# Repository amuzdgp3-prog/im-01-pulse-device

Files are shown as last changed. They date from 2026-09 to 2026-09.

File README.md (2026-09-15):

# ИМ-01 — устройство учёта импульсов для игровых аппаратов

Отдельный модуль к системе обслуживания аппаратов `2.apixspb.ru`. Устройство слушает импульсные
выходы монетоприёмника и купюроприёмника, копит показания в FRAM и дважды в сутки передаёт их на
сервер по LTE Cat.1. Показания идут **параллельно** ручным и в финансовую историю не пишутся.

Полное задание и спецификация: [docs/IM-01_FULL_BRIEF.md](docs/IM-01_FULL_BRIEF.md).

## Где что лежит

| Папка | Что там |
| --- | --- |
| `docs/` | задание, отчёты по шагам проверки, графики |
| `sim/` | аналоговая симуляция (ngspice): схемы, прогонщик, сводка результатов |
| `firmware/` | прошивка MCU (шаг 3, пока пусто) |
| `hardware/` | проект KiCad (шаг 5, пока пусто) |
| `server-contract/` | заметки по серверной части; сама реализация — в репозитории `2.apixspb.ru` (шаг 2) |

## Состояние по плану проверки (§9)

| Шаг | Что | Статус |
| --- | --- | --- |
| 1 | Аналоговая симуляция | **сделан** — [отчёт](docs/step1-analog-sim.md); виртуальная модель всего устройства — `sim/run_final.py` |
| 2 | Серверная часть в `2.apixspb.ru` | отложена владельцем: сначала железо |
| 3 | Прошивка в Renode | не начат |
| 4 | Сквозная проверка | не начат |
| 5 | Плата в KiCad | **сделана** — [описание](docs/hardware.md), файлы для JLCPCB в `hardware/fab/`; нужно ревью инженером перед заказом |

Перечень комплектующих с ценами LCSC и в РФ: [docs/ИМ-01_перечень_комплектующих.xlsx](docs/ИМ-01_перечень_комплектующих.xlsx).

## Как повторить симуляцию

```bash
sudo apt-get install -y ngspice
python3 sim/run_sim.py        # ~1 минута; matplotlib — по желанию, для графиков
```

Результат — `sim/results_auto.md` и графики в `sim/out/`.

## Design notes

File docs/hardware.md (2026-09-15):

# ИМ-01 — плата: схема, трассировка, файлы для производства

Ревизия A, 15.09.2026. Всё генерируется из одного файла `hardware/design.py`: схема, плата и перечень
не могут разойтись. Как пересобрать — в конце документа.

## Коротко

- Плата 80×55 мм, 2 слоя, 1.6 мм, 108 элементов, из них 90 монтируются. Всё на верхней стороне.
- Модем **Quectel EG800K-EU** (LTE Cat.1 bis, диапазоны B1/B3/B5/B7/B8/B20/B28).
- Проверки: ERC схемы — 0 ошибок; DRC платы — 0 нарушений; сверка платы со схемой — 0 расхождений.
  Состояние разводки — в конце документа.
- Комплектующие: около 840 ₽ на плату при партии 500 шт. (подробно — в
  [ИМ-01_перечень_комплектующих.xlsx](ИМ-01_перечень_комплектующих.xlsx)).
- Файлы для заказа на JLCPCB — `hardware/fab/`.

**Перед заказом партии в 500 штук плату должен посмотреть глазами инженер-схемотехник** (IM-01 §9
шаг 5: «плату на 500 шт не отправлять в производство без ревью глазами»). Сначала — 5–10 штук на пилот.

## Что на плате

| Блок | Детали | Зачем |
| --- | --- | --- |
| Вход питания 9–30 В | J1 (JST VH), F1 0.5 А/60 В, D1 SS36, D2 SMBJ33A, C1 47 мкФ | предохранитель, защита от переполюсовки и выбросов, гашение звона кабеля |
| Преобразователь | U1 LMR16020 (вход до 60 В), L1 10 мкГн, D3 SS36 | 3.84 В для модема, 600 кГц |
| VBAT модема | C8, C9, C33 — полимер 470 мкФ; массив 22 мкФ…1.8 пФ; D4 5.1 В | держит ≥ 3.4 В при пачках передачи до 2 А |
| Питание MCU | D5 BAT54, C14 470 мкФ, U2 ME6211 3.3 В | MCU и FRAM отделены от модема диодом: не проседают при передаче и живут ~50 мс после пропадания 12 В |
| Датчик 12 В | R6/R7 100к/10к → АЦП MCU | MCU узнаёт о пропадании питания за 0.3 мс |
| MCU | U3 STM32G030K8 (64 КБ) | два таймера на вход: захват фронтов + аппаратный счётчик |
| FRAM | U4 FM25L16B | счётчики, запись на каждый импульс, от 2.7 В |
| Входы МОНЕТА / КУПЮРА | J2 / J3 (JST XH на 2 и 3 контакта — не перепутать), 2.2 кОм, 2× 1N4148, EL817, 4.7 кОм, RC 10 кОм/100 нФ | гальваническая развязка, защита от ошибок монтажа |
| Модем | U7 EG800K-EU, U9 TXS0102 (уровни 1.8 ↔ 3.3 В), Q1/Q2 (PWRKEY, RESET) | передача 2 раза в сутки |
| SIM | J4 nano-SIM с откидной крышкой, U8 SRV05-4, 22 Ом, 15 кОм | карта не выпадет от вибрации |
| Антенна | R26 + места C28/C29 под согласование, J5 U.FL | линия 50 Ом (1.0 мм, зазор 0.2 мм) |
| Индикация | D10 зелёный — импульс, D11 красный — сеть; SW1 — выгрузка | проверка на монтаже |
| Производство | J6 площадки Tag-Connect (SWD), TP1–TP13 | прошивка и проверка без разъёмов |

## Решения, принятые при разработке платы

1. **Модем EG800K-EU вместо Air780E.** У китайского Air780E нет диапазона B20 (800 МГц — покрытие в
   посёлках) и B7. У Air780EU документации нет в открытом доступе. EG800K-EU того же размера, с полной
   документацией Quectel, $4.80.
2. **Транслятор уровней TXS0102.** Логика EG800K — 1.8 В, MCU — 3.3 В. Сторона модема питается от его
   VDD_EXT: пока модем выключен, транслятор отключён и MCU не запитывает модем через линию.
3. **Преобразователь на 60 В** вместо MP1584 (тот держит только до 28 В) — по результатам симуляции шага 1.
4. **Три полимерных конденсатора 470 мкФ на VBAT** — у EG800K минимум 3.4 В (у Air780E было 3.3 В).
5. **Питание MCU через диод с отдельным накопителем.** Даёт ~50 мс работы после пропадания 12 В —
   этого хватает дописать счётчики в FRAM. Отдельный ключ отключения модема стал не нужен.
6. **Каждый вход на двух выводах MCU.** Аппаратный счётчик фронтов (TIM1/TIM3) считает без участия
   ядра — гарантия из §2. Захват времени фронтов с DMA (TIM16/TIM17) даёт проверку длительности ≥ 15 мс.
7. **Разъёмы монеты и купюры разные** (2 и 3 контакта). Каналы невозможно перепутать, а у них разный
   вес импульса.
8. **Отладочный UART модема на точки не выведен.** Его дорожки резали заливку питания модема.
   Прошивка модема обновляется через USB (TP9–TP12), как рекомендует Quectel.

## Разводка

Три цепи разведены по заданной геометрии и зафиксированы (IM-01 §9 шаг 5):

- **антенна** — прямая линия 1.0 мм от вывода 35 модема через R26 к U.FL, со строчкой переходных на
  землю вдоль неё;
- **коммутирующий узел преобразователя** — короткие широкие дорожки SW → дроссель и диод;
- **путь VBAT** — сплошная медная заливка от дросселя через все накопительные конденсаторы к выводам
  42/43 модема (задание требует ≥ 2 мм).

Остальное развёл Freerouting. Нижний слой — сплошная земля, слои сшиты переходными.

## Виртуальная модель

`sim/run_final.py` — одна схема ngspice на всё устройство с окончательными номиналами. Результаты — в
`sim/results_final.md`; все 5 сценариев проходят:

| Проверка | Результат | Требование |
| --- | --- | --- |
| VBAT при передаче, худший случай | 3.53 В | ≥ 3.4 В (EG800K) |
| Выброс VBAT при сбросе нагрузки | ≤ 3.97 В | ≤ 4.3 В |
| 3.3 В MCU при передаче | ровно 3.3 В | не проседает |
| Задержка входов NO / NC | 1.3–2.2 мс | < 3 мс |
| Спайк 0.2 мс | 2.2 В / 0.2 В на входе MCU | не доходит до порога |
| Датчик пропадания 12 В | 0.3 мс | раньше, чем MCU потеряет питание |
| MCU после пропадания 12 В | 47–51 мс до 2.7 В | ≥ 3 мс на запись FRAM |

## Файлы для производства (`hardware/fab/`)

| Файл | Что с ним делать |
| --- | --- |
| `im01_gerbers.zip` | загрузить на jlcpcb.com: 2 слоя, 1.6 мм, 1 oz, переходные «tented» |
| `im01_bom_jlcpcb.csv` | перечень для монтажа (SMT Assembly) |
| `im01_cpl_jlcpcb.csv` | координаты деталей для монтажа |
| `im01_schematic.pdf` | схема |
| `im01_assembly_top.pdf` | сборочный чертёж |
| `im01_3d_top.png`, `im01_3d_bottom.png`, `im01.step` | внешний вид, модель для проверки корпуса |

При заказе монтажа на JLCPCB проверить в их предпросмотре повороты деталей — у библиотек KiCad и
JLCPCB бывает расхождение на 90/180° (особенно у EL817, SOT-23, SIM-держателя, модема). Модем EG800K-EU
на складе JLCPCB почти отсутствует — его поставлять давальчески (дистрибьютор Quectel).

## Что проверяется только на пилоте

- реальные импульсы TB74 / VN-5 / EU-9 (осциллограф), шум у соленоида;
- VBAT при реальной передаче EG800K и частота среза LMR16020 с 1410 мкФ;
- уровень сигнала антенны в металлическом корпусе, подбор C28/C29;
- типы разъёмов акцепторов для Y-жгута.

## Как пересобрать

```bash
cd hardware
python3 check_design.py      # design.py сверяется с библиотеками
python3 gen_sch.py           # схема
python3 gen_pcb.py           # расстановка
python3 route.py             # трассировка: ручные цепи + Freerouting
python3 fix_gnd.py           # досоединение земли по отчёту DRC (при необходимости)
python3 fab.py               # файлы для производства
python3 gen_bom.py 500       # перечень с ценами → docs/
```

## Состояние разводки (15.09.2026)

| Проверка | Результат |
| --- | --- |
| ERC схемы | 0 ошибок (2 предупреждения: копия символа 2N7002 отличается от библиотечной — без влияния) |
| DRC платы | **0 нарушений, 0 неподключённых площадок** |
| Сверка платы со схемой | **0 расхождений** |
| Шелкография | 66 наложений надписей и 38 надписей на меди — косметика: завод обрезает шелкографию с площадок, на мелочи обозначения налезают друг на друга. Сборочный чертёж `im01_assembly_top.pdf` читается полностью |
| Модели 3D | есть у всех деталей, кроме разъёма питания J1 (JST VH): в библиотеке KiCad модели нет |

Разводка сделана автоматически по правилам из задания; решения, которые стоит посмотреть на ревью:

- линия антенны — 1.0 мм с зазором 0.2 мм до земли (≈ 54 Ом на FR4 1.6 мм), длина ~8 мм; П-цепь
  R26/C28/C29 у самого разъёма;
- силовая петля LMR16020 (вход → SW → дроссель → диод → земля) — самая короткая, какую позволила
  расстановка; стоит проверить глазами ширину и путь земляного возврата D3;
- земля верхнего слоя разрезана сигнальными дорожками на куски, каждый сшит с цельной землёй нижнего
  слоя переходными отверстиями (всего ~250).

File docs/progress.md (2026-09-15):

# ИМ-01 — промежуточный отчёт (15.09.2026)

## Что сделано

**Шаг 1 — аналоговая симуляция.** Готова, отчёт: [step1-analog-sim.md](step1-analog-sim.md). Схема
проверена в ngspice; по результатам внесены поправки:

- подтяжка оптопары 4.7 кОм;
- последовательный диод в цепи светодиода — чтобы ошибка монтажа не ломала аппарат;
- преобразователь на 60 В вместо MP1584;
- диод Шоттки на 60 В;
- датчик пропадания 12 В.

**Решения владельца от 15.09:**

- Порог длительности импульса — 15 мс. По документации самый короткий импульс акцепторов 25 мс,
  у монетника есть переключатель 25–100 мс.
- Передача показаний в нерабочие часы: 22:30 и 07:30, каждому устройству — сдвиг 0–10 мин.
  Синхронизация iVend в `2.apixspb.ru` перенесена на те же часы (DECISION-076, уже в работе на сервере).
- Сначала делается железо: проверенная схема, плата для производства, перечень деталей.

**Модем заменён: Quectel EG800K-EU вместо Air780E.**

- У китайского Air780E нет диапазонов B20 (800 МГц — покрытие в посёлках) и B7.
- У европейского Air780EU документации не нашлось нигде.
- EG800K-EU: Cat.1 bis, B1/B3/B5/B7/B8/B20/B28, тот же размер 17.7×15.8 мм, полная документация
  Quectel, $4.80.
- Отличия от Air780E, учтённые в схеме:
  - логика модема 1.8 В — добавлен транслятор уровней TXS0102;
  - VBAT от 3.4 В — добавлен третий полимерный конденсатор 470 мкФ;
  - PWRKEY ≥ 700 мс, RESET_N ≥ 300 мс.

**Схема** (`hardware/`) генерируется из одного файла `design.py`:

- 110 деталей, 67 цепей;
- все артикулы LCSC подобраны, наличие и цены сверены по каталогу JLCPCB/LCSC;
- проверка `check_design.py`: каждый вывод есть в символе, каждая площадка — в посадочном месте,
  ошибок нет.

**Плата** 80×55 мм, 2 слоя:

- расстановка сделана, осталось поправить несколько наложений;
- надписи apixspb.ru, «ИМ-01», подписи разъёмов;
- правила под JLCPCB, линия антенны рассчитана на 50 Ом.

## Что осталось

1. Добить расстановку до нуля нарушений DRC (осталось ~15 мелких наложений).
2. Трассировка: антенна, силовая петля преобразователя и VBAT — руками, остальное — автотрассировщик.
   Затем заливки, DRC, сверка платы со схемой.
3. Файлы для производства: гербер-файлы, сверловка, BOM и файл расстановки для JLCPCB, PDF схемы,
   3D-вид платы.
4. Пересчитать «виртуальную модель» с окончательными номиналами — симуляцию всего устройства.
5. Прошивка (шаг 3) — после платы.

## Что нужно от владельца

- **Модем.** На JLCPCB/LCSC всего 32 шт. EG800K-EU. Для партии 500 шт. нужно заказать у дистрибьютора
  Quectel и отдать на завод давальческой поставкой. Альтернатива — SIMCom A7670E: есть на складе, но
  $8.70 и другой корпус, стоимость устройства упирается в лимит 1709 ₽.
- **GitHub.** На машине настроен только SSH-ключ, создать новый репозиторий с него нельзя. Создайте
  пустой закрытый репозиторий `im-01-pulse-device` — я запушу в него.
- **Перечень деталей** проверить на наличие у ваших поставщиков. Артикулы — в `hardware/design.py`.

## Как продолжить

```bash
cd /home/s/Work/im-01-pulse-device/hardware
python3 check_design.py && python3 gen_sch.py && python3 gen_pcb.py
kicad-cli pcb drc --severity-all -o drc.rpt im01.kicad_pcb
```

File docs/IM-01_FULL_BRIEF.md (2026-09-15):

# ИМ-01: задание и спецификация (единый файл)

**Ассистент, читай этот файл целиком — он самодостаточный.** Ничего дополнительно искать не нужно:
в репозитории этого документа нет, предыдущее обсуждение тебе недоступно. Всё необходимое ниже.

Визуальная версия спецификации (опционально, читается по ссылке): <https://claude.ai/artifact/Nbtftt8PGQxtJA64Jm9ssD>

---

## 0. Что от тебя нужно

Спроектировать и виртуально проверить устройство учёта импульсов для игровых аппаратов, затем
реализовать серверную часть приёма данных в этом репозитории.

**Начинай с шага 1 плана проверки (§8) — с аналоговой симуляции, не с платы и не с кода.** Порядок
в §8 выбран по принципу «сначала самое дешёвое и самое показательное», не меняй его без причины.

### Чего не делать ни при каких условиях

1. **Не предлагать комбо-модуль** (MCU внутри модема) как экономию. Уже рассматривали и отклонили,
   причина в §2 — она жёсткая, а не вкусовая.
2. **Не писать в `services` и не трогать счётчики игр.** Приём показаний не создаёт обслуживание и
   не участвует в расчёте выручки (§7).
3. **Не отдавать автороутеру три цепи**: трассу до u.FL, коммутирующий узел преобразователя, путь
   VBAT (§8 шаг 5).
4. **Не считать 1000 мкФ на VBAT проверенной величиной** — это отправная точка для симуляции (§5.2).
5. **Не заменять ручные показания** автоматическими. Решение владельца — они идут параллельно.

### Что решать самому, а что спрашивать

- **Сам:** номиналы пассивных элементов, выбор конкретных микросхем внутри заданных классов,
  структура кода и тестов, порядок действий внутри одного шага.
- **Спросить владельца:** оператора и тариф M2M на 500 SIM; подтверждение перед реализацией
  серверного контракта (требование правил репозитория); любое изменение решений из §3.
- **Проверить на пилоте, а не угадывать:** всё из §10.

---

## 1. Контекст

Репозиторий — система обслуживания игровых аппаратов `2.apixspb.ru` (Node 22 + Fastify +
PostgreSQL 16 + PWA на React/Vite). Сейчас учёт ручной: техник вносит показания механического
счётчика с обязательным фото.

Проектируемое устройство слушает импульсные выходы монетоприёмника и купюроприёмника, накапливает
показания и передаёт их на сервер 2 раза в сутки. Одно устройство на аппарат.
**Партия 500 шт, лимит цены 1709 ₽/шт**, расчётная себестоимость 788–1228 ₽.

Стадия: **проектирование**. Железо, прошивка и серверная часть не реализованы. Контракт API
утверждён владельцем, но не написан.

### Оборудование на аппаратах

| Устройство | Тип | Питание | Интерфейсы | Импульс |
| --- | --- | --- | --- | --- |
| TOP TB74 | купюроприёмник | 12 В | Pulse / RS232 / ccTalk / ID003 | конфигурируется |
| ICT/VNTec VN-5 | монетоприёмник | 12 В, 0.5 А | Pulse / RS-232 | 25/50/100 мс, NO/NC, ≤12 типов монет, 2 монеты/с |
| Coinsolve EU-9 | монетоприёмник | 12 В | Pulse / RS-232 | 25/50/80 мс, NO/NC, INHIBIT, ≤12 типов |

На аппарате один монетоприёмник и один купюроприёмник → **два входных канала**.

---

## 2. Жёсткое требование владельца

> «Импульсы не должны теряться, иначе финансовая история окажется неверной — это недопустимо.»

Разобраны три механизма потерь:

| Механизм | Природа | Решение | Остаток |
| --- | --- | --- | --- |
| Окно записи в память | Счётчик сохранялся не чаще раза в 60 с ради износа flash | **FRAM**: атомарная запись, без стирания и лимита циклов, сохранение на каждый импульс | ноль |
| Голодание обработчика при передаче | На комбо-модуле счёт и радиостек делят одно ядро; занятость >25 мс теряет фронт | **Отдельный MCU**, линия импульса на вход таймера в режиме внешнего счётчика | ноль |
| Непроверяемость пульс-протокола | Голый фронт на проводе: нет CRC, кадрирования, подтверждения | Фильтр по длительности ≥10 мс, опторазвязка, витая пара, счётчики отбракованных импульсов в батче | мал, но не ноль |

**Почему аппаратный таймер, а не прерывание.** Регистр счётчика таймера инкрементируется схемой
таймера без участия ядра. Даже при полностью заблокированной прошивке (шторм прерываний, занятый
обмен с модемом, ожидание сети) счёт продолжается корректно, ядро читает регистр позже. Это гарантия
схемы, а не обещание программы. На комбо-модуле такой гарантии нет конструктивно — отсюда решение 3
в §3.

**Почему пропадание питания не создаёт окна потери.** Акцептор и устройство сидят на одной линии
12 В, поэтому монета физически не может быть принята, когда у акцептора нет питания — они пропадают
вместе. Ёмкость на входе даёт запас в десятки миллисекунд, чего хватает записать последний импульс.

**Чего гарантировать нельзя — и не надо обещать обратного.** Пульс-протокол непроверяем в принципе.
Полностью верифицируемый счёт даёт только ccTalk/ID003 на TB74, но режимы акцептора
взаимоисключающие: перевод на serial ломает штатный подсчёт самого автомата. Это отдельный и
гораздо больший проект, владельцу озвучено. Остаточная погрешность контролируется сверкой с ручными
показаниями.

---

## 3. Принятые решения — не пересматривать без владельца

| № | Решение | Обоснование |
| --- | --- | --- |
| 1 | Показания идут **параллельно** ручным, не заменяют их | Решение владельца. Снимает требования к RTC и к абсолютной точности; расхождение двух источников само является сигналом |
| 2 | **Пассивный** отбор сигнала, INHIBIT не подключается | Устройство не управляет акцептором и не встаёт в разрыв штатной проводки — не может нарушить работу аппарата |
| 3 | **Дискретная** схема: отдельный MCU + отдельный модем | Требование §2. Комбо (Air202/LuatOS, MC60/OpenCPU) отклонено |
| 4 | Модем **LTE Cat.1 bis** (Air780E-класс) | Оптом $2.50–12.50 против NB-IoT $5–14, то есть на уровне 2G. Обычное LTE-покрытие, не гасится, полоса достаточна для OTA. 2G отклонён (сеть гасится, модули с OpenCPU сворачиваются); NB-IoT отклонён (дороже всех, развёрнут выборочно, медленный OTA) |
| 5 | Антенна **выводится за пределы** металлического корпуса (u.FL → пигтейл → SMA) | Снимает клетку Фарадея конструктивно. Именно поэтому преимущество NB-IoT (~20 дБ на проникновение) перестало быть аргументом |
| 6 | Только **накопительные счётчики**, без лога отдельных событий | Решение владельца. Лог дал бы ~90 млн строк и +10–15 ГБ в год. Накопительный счётчик вдобавок самовосстанавливается: потерянный батч не теряет деньги |
| 7 | Передача **2 раза в сутки** в заданные часы | Совпадает с расписанием синхронизации iVend (DECISION-032). Часы выставляются на простой аппарата |
| 8 | **Без провижининга** на производстве, идентификация по **ICCID** | Решение владельца. ICCID уже уникален в любой SIM; привязка «устройство → аппарат» ведётся на сервере |
| 9 | **Съёмный** nano-SIM | Оператор не выбран; смена оператора не должна требовать переделки платы |
| 10 | Устройство передаёт **импульсы, а не рубли** | Вес импульса — свойство настройки акцептора, живёт на сервере и штампуется в принятую строку (логика DECISION-001). Неверный вес правится на сервере, а не выездом к 500 аппаратам |
| 11 | RTC и суперконденсатор **исключены** | Следствие решения 6: накопительный снимок не привязан ко времени суток, достаточно серверного `received_at` |

---

## 4. Спецификация: входной каскад (2 канала)

Устройство висит параллельно входу штатного контроллера, поэтому добавленная нагрузка должна быть
мала относительно возможностей открытого коллектора акцептора (десятки мА).

| Параметр | Значение |
| --- | --- |
| Токоограничивающий резистор на светодиод оптопары | 2.2 кОм → ≈5 мА |
| Оптопара | PC817-класс, CTR ≥ 50 % |
| Обратный диод параллельно светодиоду оптопары | **обязателен** (U_обр PC817 ≈ 6 В) |
| Фильтр на выходе оптопары | 10 кОм + 100 нФ ≈ 1 мс |
| Подтяжка выхода оптопары | на `VDD_EXT` MCU, **не** на VBAT |
| Режим NO/NC | инверсией в прошивке, схема общая |

Обратный диод — не перестраховка: на 500 аппаратах монтажник где-то перепутает провода, и 12 В в
обратном включении убивают светодиод оптопары. Деталь за 1 ₽ против выезда.

## 5. Спецификация: питание

| Параметр | Значение |
| --- | --- |
| Входное напряжение | 9–30 В (покрывает 12 В, 24 В и выбросы) |
| Выход преобразователя | 3.8 В, ≥2 А (MP1584-класс) |
| Ёмкость на VBAT | ≥1000 мкФ low-ESR + 10–22 мкФ керамика у выводов модуля |
| Защита входа | предохранитель + защита от переполюсовки + TVS |
| Средний ток | ≈100 мА |

Широкий входной диапазон выбран намеренно: вопрос «питание с линии акцептора или с отдельного
отвода» решается на монтаже и не блокирует разводку.

### 5.2 Требует проверки симуляцией, не принимать на веру

Цифра **1000 мкФ — инженерная отправная точка, а не проверенное значение**. Ёмкость должна покрывать
только время реакции петли преобразователя (≈10–50 мкс), потому что при частоте коммутации
0.5–1.5 МГц петля успевает отреагировать внутри пачки передачи. Если бы ёмкость должна была нести
всю пачку целиком, требовалось бы `C ≥ I·Δt/ΔV` = 2 А × 577 мкс / 0.2 В ≈ 5800 мкФ.

Что происходит с выбранным преобразователем — считает ngspice (§8 шаг 1). Отдельно учесть: у LTE
Cat.1 нет TDMA-структуры 577 мкс как у GSM, пики мягче, поэтому требование может оказаться слабее.
Скорректировать эту таблицу по результатам симуляции — ожидаемый результат, а не провал.

## 6. Спецификация: диагностика, монтаж, закупка

- **LED1** — мигает на каждый принятый импульс: монтажник бросает монету и видит, что отбор работает.
- **LED2** — статус сети и последней выгрузки.
- **Кнопка** — принудительная выгрузка: весь путь до сервера проверяется на монтаже, а не через 12 ч.
- Втроём ≈8 ₽. На 500 установок — самая выгодная позиция в спецификации.
- **Y-переходник**: штатные провода не резать. С одной стороны разъём в акцептор, с другой гнездо под
  оригинальный жгут, отвод на `impulse`, `GND`, `+12 В`. Разъёмы ключёванные, монтаж обратим.

| Позиция | ₽/шт при 500 |
| --- | --- |
| MCU STM32C0/G0 | 50–80 |
| FRAM | 30–60 |
| Модем LTE Cat.1 bis | 280–450 |
| Оптопары 2 кан. + диоды + RC | 35–45 |
| Преобразователь 2 А + защита + 1000 мкФ | 55–75 |
| Антенна + пигтейл + SMA | 45–65 |
| Держатель nano-SIM + ESD | 20 |
| 2 LED + кнопка | 8 |
| Плата, 2 слоя | 45–65 |
| SMT-сборка turnkey | 110–180 |
| Корпус | 70–110 |
| Y-жгут + разъёмы | 40–70 |
| **Итого** | **788–1228** (лимит 1709) |

Разовые затраты (разработка, прототипы, оснастка) не входят. SIM и тариф — операционные расходы.

## 7. Требования к прошивке

1. **Счёт.** Линия импульса — на вход таймера в режиме внешнего счётчика. Импульс короче **10 мс**
   не засчитывается, а инкрементирует счётчик отбракованных.
2. **Хранение.** Четыре счётчика в FRAM: принятые и отбракованные, по монете и по купюре. Запись на
   каждое изменение. Счётчики не сбрасываются никогда — ни при перезагрузке, ни при потере питания.
3. **Передача.** 2 раза в сутки в заданные часы. Регистрация в сети → `POST` → при HTTP 2xx
   фиксируется подтверждённый `seq`.
4. **Сбой связи.** Несколько повторов с нарастающей паузой, дальше ожидание следующего окна.
   Накопительный характер счётчика означает, что пропуск окна ничего не теряет.
5. **Watchdog.** Перезагрузка при зависании обмена с модемом. Счётчики в FRAM, перезагрузка бесплатна.
6. **OTA.** Обновление прошивки по сотовому каналу входит в объём первой версии: без него ошибка в
   прошивке означает 500 выездов.

## 8. Серверный контракт (утверждён владельцем, не реализован)

`POST /api/pulse/batch`, полезная нагрузка ≈120 байт:

```json
{
  "iccid": "8970101234567890123",
  "seq": 412,
  "coinPulsesTotal": 18340,
  "billPulsesTotal": 2255,
  "coinPulsesRejected": 3,
  "billPulsesRejected": 0
}
```

Три новые таблицы — **зеркала уже работающих и протестированных в этом репозитории**. Копируй их
структуру, а не изобретай свою:

| Новая таблица | С образца | Назначение |
| --- | --- | --- |
| `pulse_devices` | `terminals` | Устройство опознаётся по `iccid` (UNIQUE) |
| `pulse_device_bindings` | `terminal_bindings` | Интервальная история «устройство → аппарат»: `EXCLUDE USING gist` по `tstzrange`, одно активное на аппарат. Перестановка устройства не портит прошлые периоды |
| `pulse_batches` | `cashless_transactions` | Снимки счётчиков; идемпотентность по `(device_id, seq)` через UNIQUE + `ON CONFLICT DO NOTHING`; `forbid_delete`; статус `UNMATCHED` при непривязанном ICCID |

Миграция — новый файл в `api/src/migrations/` с номером больше последнего.

Деньги считаются на сервере: `(coinPulsesTotal − предыдущий) × pulse_value_applied`. Вес импульса
штампуется в строку, поэтому перенастройка акцептора не переписывает деньги за прошлые периоды (та
же логика, что в DECISION-001 после пересмотра).

**Граница данных (критично).** Приём не создаёт `services`, не трогает счётчики игр и не участвует в
расчёте выручки. Это ровно граница DECISION-008, по которой работает импорт безналичных транзакций.
Официальной финансовой историей остаются ручные показания.

**Предупреждение о взаимоблокировках.** `pulse_device_bindings` использует тот же
`EXCLUDE USING gist`, что `terminal_bindings`, и попадает под протокол блокировок DECISION-005 —
порядок взятия advisory-локов надо соблюсти, иначе возможны взаимоблокировки с matcher'ом безнала.

**Аутентификация.** Существующие роуты идут через staff-JWT (`app.authenticate` →
`request.jwtVerify()`), устройство сессию сотрудника держать не может. Решение на время: общий
bearer-токен прошивки, и сервер принимает данные только для ICCID, который админ уже привязал к
аппарату (неизвестный ICCID → `UNMATCHED`, как неизвестный терминал сейчас). Соразмерно потому, что
устройство не пишет в финансовую историю: худший исход при утечке токена — шум в таблице сверки.
После выбора оператора перейти на приватный APN — тогда секрет на устройстве не нужен вообще.

**Тестов на этот слой нет по определению, он новый** — их надо написать (критерии в §9 шаг 2).

---

## 9. План проверки с критериями приёмки

Инструменты (проверено на Ubuntu 24.04 с root-правами):

```bash
# шаг 1 — аналог
apt-get install -y ngspice && pip3 install PySpice

# шаг 2 — сервер (контейнер не нужен, поднимается локально теми же миграциями)
apt-get install -y postgresql-16
cd api && npm install

# шаг 3 — прошивка
apt-get install -y gcc-arm-none-eabi
# Renode 1.17.0 (07.09.2026), github.com/renode/renode/releases:
#   renode_1.17.0_amd64.deb  либо  renode-1.17.0.linux-portable.tar.gz
pip3 install robotframework

# шаг 5 — плата (в самом noble только KiCad 7.0.11, для 9 нужен PPA)
add-apt-repository -y ppa:kicad/kicad-9.0-releases && apt-get update
apt-get install -y kicad
```

### Шаг 1. ngspice — аналог

Проверить: входной каскад (импульс 25 мс при 12 В даёт чистый логический переход, спайк 0.2 мс — не
даёт; оба режима NO и NC), просадку VBAT при импульсной нагрузке модема, переполюсовку и выброс на
входе.

**Приёмка:** задержка фильтра < 3 мс (много меньше 25 мс); спайк 0.2 мс подавлен ниже логического
порога; VBAT не опускается ниже минимума питания модуля по даташиту ни в одном цикле; ни один
элемент не выходит за предельные режимы. Если 1000 мкФ не хватает — скорректировать §5.

### Шаг 2. Серверная часть

Поднять postgresql-16, прогнать миграции репозитория, реализовать контракт §8.

**Приёмка** — тесты в стиле репозитория (`npx tsx --test --test-concurrency=1 tests/*.test.ts`):

- повторный `POST` с тем же `(iccid, seq)` вставляет строку один раз;
- батч с неизвестным ICCID сохраняется со статусом `UNMATCHED` и не отбрасывается;
- сопоставление идёт по привязке, действовавшей на момент приёма, а не по текущей;
- убывание накопительного счётчика отклоняется (счётчики монотонны);
- `services` и счётчики игр не изменяются ни одним из сценариев.

### Шаг 3. Прошивка в Renode

Инъекция в GPIO: N корректных импульсов (25/50/80/100 мс) + M спайков короче 10 мс.

**Приёмка:** счётчик принятых = ровно N, отбракованных = ровно M. **Тот же тест обязан пройти во
время идущей выгрузки** — это проверка того самого требования §2, из-за которого отказались от комбо.

### Шаг 4. Сквозная проверка

Renode (прошивка) → AT-заглушка на хосте → реальный API → PostgreSQL.

**Приёмка:** число импульсов, поданных в GPIO, совпадает с числом в строке БД; обрыв связи посреди
передачи не теряет и не удваивает показания после восстановления.

### Шаг 5. KiCad

Схема → расстановка → руками развести и зафиксировать (lock) 3 критичные цепи → автороутер на
остальное → полигон земли → DRC → гербера.

Три цепи, которые разводятся **только руками**:

1. трасса до u.FL — контролируемые 50 Ω, короткая и прямая, целый полигон земли под ней;
2. коммутирующий узел buck-преобразователя — критична площадь петли (высокая di/dt);
3. путь VBAT — несёт броски до 2 А, ширина по падению и нагреву.

**Приёмка:** DRC 0 ошибок, 3 критичные цепи разведены вручную, разводка прочитана человеком. Плату
на 500 шт не отправлять в производство без ревью глазами, чем бы она ни была разведена.

Автороутер: Freerouting (нужна java) или KiCadRoutingTools (требует KiCad 9/10; 428 звёзд, 4123
коммита, релизы с бинарниками, но в официальный PCM ещё не принят, и по README нет push-and-shove,
слепых/погребённых переходных и правил по областям платы).

---

## 10. Что проверяется только пилотом

Пилот — 5–10 устройств на отладочных платах, до заказа серийной платы:

1. Реальная ширина, полярность и настройки переключателей на TB74, VN-5, EU-9 (осциллограф).
   **Здесь же проверяется главное:** запрограммированы ли акцепторы как «1 импульс = один
   фиксированный кредит». При накопительных счётчиках (решение 6) номинал из суммы импульсов не
   восстанавливается. Если номиналы заданы разным числом импульсов — потребуется перепрограммирование
   500 аппаратов.
2. Реальный шум на пульс-линии рядом с соленоидом монетоприёмника.
3. Запас по току на линии 12 В акцептора → откуда брать питание.
4. Уровень сигнала внутри металлического корпуса с вынесенной антенной на нескольких точках.
5. Типы разъёмов акцепторов для Y-жгута.
6. Обновление прошивки по воздуху.
7. Сверка накопленного счётчика с ручными показаниями за период — единственная проверка остаточной
   погрешности пульс-протокола.

## 11. Открытые вопросы

| Вопрос | Кто закрывает |
| --- | --- |
| Оператор и тариф M2M на 500 SIM, приватный APN | владелец |
| Конкретный SKU модема + подтверждение доступности под серию (не EOL) | запрос поставщику |
| Программирование акцепторов: 1 импульс = один фиксированный кредит? | пилот, §10 п.1 |
| Точка отвода питания | пилот, §10 п.3 |
| Уровень логики `VDD_EXT` выбранного MCU для подтяжек | даташит при разработке платы |
| Типы разъёмов акцепторов | пилот, §10 п.5 |

---

## 12. Правила репозитория — обязательны

Читаются в `CLAUDE.md` и `.claude/rules/modularity.md`. Коротко:

- План перед изменением, затрагивающим больше одного модуля, — **и ждать подтверждения владельца**.
- Один слой за раз: типы → миграции → API-роуты → клиент. Не смешивать в одном шаге.
- Отдельный коммит на каждый логически завершённый шаг, а не один большой в конце.
- Смена контракта (API, схема БД, формат данных) — сначала показать, что меняется, и дождаться
  подтверждения.
- Не трогать код, не относящийся к задаче.
- Если изменение может затронуть работающий функционал — назвать это явно.
- Все сообщения пользователю и в коде — по-русски (DECISION-028).
- Перед изменением уже реализованного поведения проверить, нет ли по нему записи `DECISION-NNN`
  в `DECISIONS.md`.

Команды проверки после изменений:

```bash
cd api && npx tsc -p tsconfig.json --noEmit     # типы API
cd web && npx tsc -b                            # типы клиента
cd api && npx tsx --test --test-concurrency=1 tests/*.test.ts
```

### Про git — внимательно

Владелец изменил правило: **пушить в GitHub после каждого логически завершённого шага**
(`git push -u origin <branch>`), отдельного разрешения на пуш спрашивать не нужно.

**В копии `CLAUDE.md` твоего репозитория может лежать старая формулировка** («коммиты только
локально, не пушить без явного указания»). Правило выше новее — владелец изменил его после того, как
эта копия была сделана; правка не попала в remote, потому что у сессии, где она делалась, не было
доступа на запись в GitHub. Приведи `CLAUDE.md` в соответствие с правилом выше отдельным коммитом.

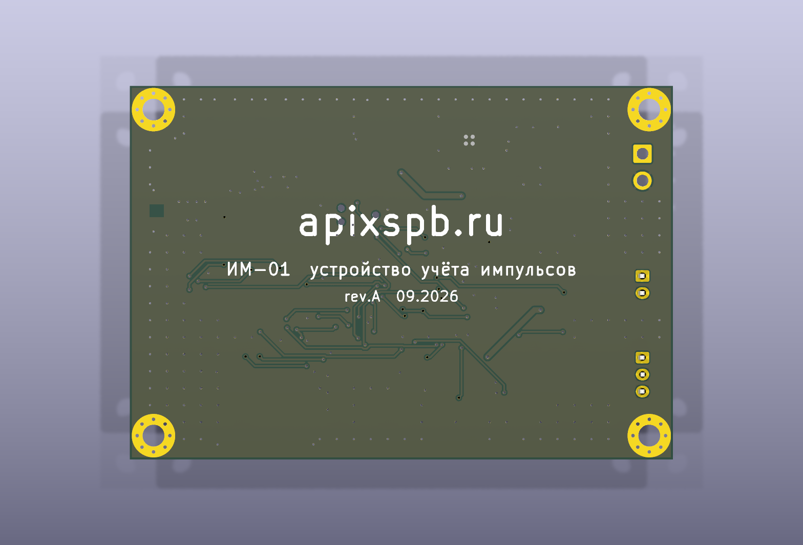
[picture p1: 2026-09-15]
hardware/fab/im01_3d_bottom.png

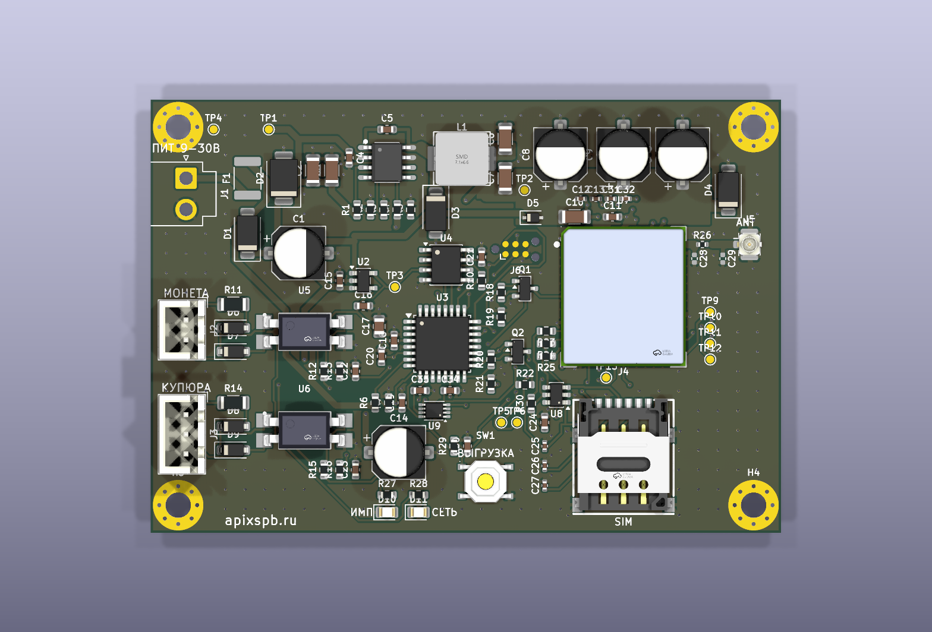
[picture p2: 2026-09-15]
hardware/fab/im01_3d_top.png

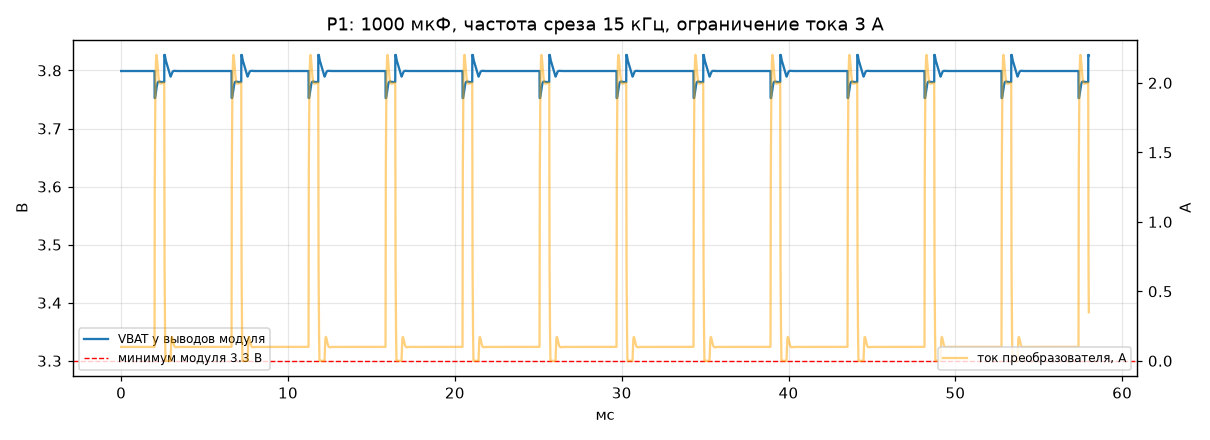
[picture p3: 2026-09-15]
docs/img/vbat_P1_15000Hz.png

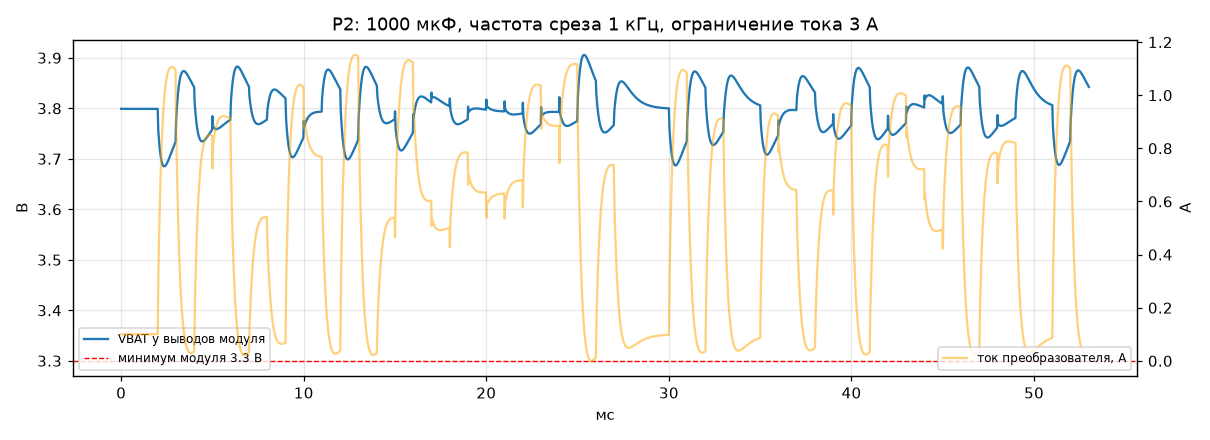
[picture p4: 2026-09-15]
docs/img/vbat_P2_1000Hz.png

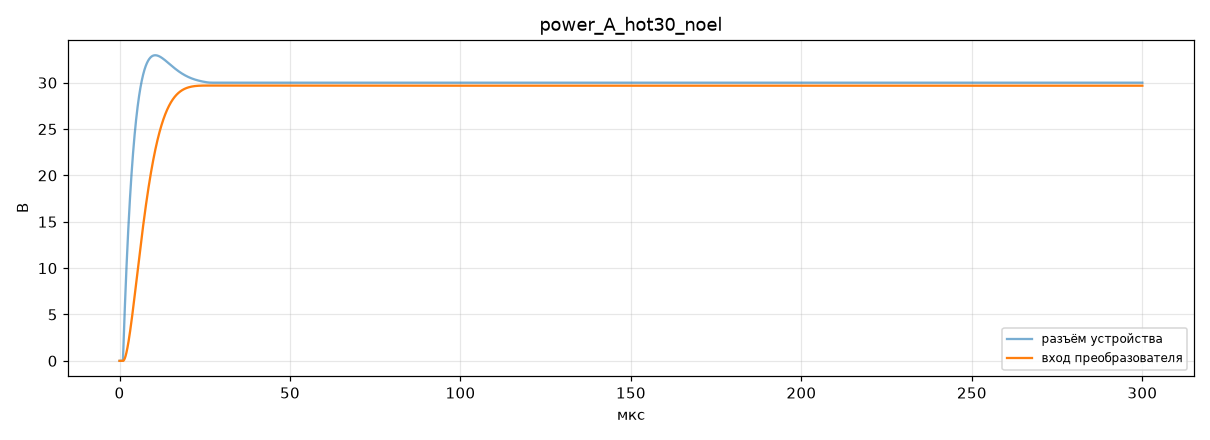
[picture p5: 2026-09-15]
docs/img/power_A_hot30_noel.png

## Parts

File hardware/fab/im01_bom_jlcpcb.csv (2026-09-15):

Comment | Designator | Footprint | LCSC Part #
B2P-VH(LF)(SN) | J1 | JST_VH_B2P-VH_1x02_P3.96mm_Vertical | C160315
0.5A/60V | F1 | Fuse_1812_4532Metric | C70113
SS36 | D1,D3 | D_SMA | C16015
SMBJ33A | D2 | D_SMB | C353366
47uF/50V | C1 | CP_Elec_6.3x7.7 | C970679
4.7uF | C2,C3 | C_1206_3216Metric | C29823
100k | R6,R19,R21 | R_0603_1608Metric | C25803
10k | R5,R7,R10,R13,R16,R22,R29 | R_0603_1608Metric | C25804
100nF | C4,C5,C11,C18,C19,C20,C21,C22,C23,C24,C30,C34,C35 | C_0603_1608Metric | C14663
LMR16020PDDAR | U1 | SOIC-8_L4.9-W3.9-P1.27-LS6.0-BL-EP | C190006
270k | R1 | R_0603_1608Metric | C22965
49.9k | R2 | R_0603_1608Metric | C23184
41.2k | R3,R4 | R_0603_1608Metric | C23166
10uH | L1 | IND-SMD_L7.3-W6.6_MHCI06030 | C207842
22uF | C6,C7,C10 | C_1206_3216Metric | C87996
470uF/6.3V | C8,C9,C14,C33 | CP_Elec_6.3x7.7 | C54321567
SMAZ5V1 | D4 | D_SMA | C154748
BAT54WS | D5 | D_SOD-323 | C3040452
1uF | C15,C16 | C_0603_1608Metric | C15849
ME6211C33M5G-N | U2 | SOT-23-5 | C82942
STM32G030K8T6TR | U3 | LQFP-32_7x7mm_P0.8mm | C724044
10uF | C17 | C_0805_2012Metric | C15850
FM25L16B-GTR | U4 | SOIC-8_3.9x4.9mm_P1.27mm | C466849
B2B-XH-A(LF)(SN) | J2 | JST_XH_B2B-XH-A_1x02_P2.50mm_Vertical | C158012
2.2k | R11,R14 | R_1206_3216Metric | C17948
1N4148W | D6,D7,D8,D9 | D_SOD-123 | C81598
EL817S1(B)(TU)-F | U5,U6 | SOP-4_L6.5-W4.6-P2.54-LS10.2-TL | C63268
4.7k | R12,R15 | R_0603_1608Metric | C23162
B3B-XH-A(LF)(SN) | J3 | JST_XH_B3B-XH-A_1x03_P2.50mm_Vertical | C144394
EG800KEULC-I03-SNNSA | U7 | LGA-109_L17.7-W15.8-AIR780E | C44008839
33pF | C12,C25,C26,C27 | C_0402_1005Metric | C1562
10pF | C13 | C_0402_1005Metric | C32949
3.9pF | C31 | C_0402_1005Metric | C1566
1.8pF | C32 | C_0402_1005Metric | C1553
TXS0102DCUR | U9 | VSSOP-8_2.3x2mm_P0.5mm | C53434
2N7002 | Q1,Q2 | SOT-23 | C8545
1k | R18,R20,R27,R28 | R_0603_1608Metric | C21190
NANO SIM XG6P H1.35 | J4 | SIM-SMD_NANO-SIM-XG6P-H1.35 | C7529386
22Ω | R23,R24,R25 | R_0603_1608Metric | C23345
15k | R30 | R_0603_1608Metric | C22809
SRV05-4 | U8 | SOT-23-6 | C2836319
0Ω | R26 | R_0402_1005Metric | C17168
U.FL-R-SMT-1(80) | J5 | U.FL_Hirose_U.FL-R-SMT-1_Vertical | C88374
зелёный | D10 | LED_0805_2012Metric | C84260
красный | D11 | LED_0805_2012Metric | C84256
TS-1187A-B-A-B | SW1 | SW-SMD_4P-L5.1-W5.1-P3.70-LS6.5-TL_H1.5 | C318884

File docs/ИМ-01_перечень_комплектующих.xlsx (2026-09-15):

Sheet: Перечень
№ | Обозначения на плате | Кол-во на плату | Кол-во на 500 плат | Номинал / тип | Производитель | Артикул производителя | Артикул LCSC | Корпус | Описание | Примечание | LCSC, $/шт | LCSC, ₽/шт | LCSC, склад | ЧипДип, ₽/шт | ЧипДип, наличие | efind (склады РФ), лучшая ₽/шт | efind: предложений с наличием | Цена для расчёта, ₽/шт | Источник цены | Сумма на 500 плат, ₽ | Ссылки
1 | J1 | 1 | 500 | ПИТАНИЕ 9-30В | JST | B2P-VH(LF)(SN) | C160315 | Through Hole,P=3.96mm | Connector Header 2 position 3.96mm Pitch 10A Through Hole -25℃~+85℃ | 1 = +, 2 = GND | 0.0457 | 3.85 | 308060 | 13.00 | 5038 шт. | 1.39 | 35 | 13.00 | ЧипДип | 6500.00 | LCSC: https://www.lcsc.com/product-detail/C160315.html ЧипДип: https://www.chipdip.ru/product/sct3961wv-02p-b2p-vh-vilka-pryamaya-na-platu-3.96mm-scondar-9000546298 efind: https://efind.ru/offer/B2P-VH?stock=1&c=rur&r=0&hp=1&opriv=0
2 | F1 | 1 | 500 | 0.5A/60V | TECHFUSE | mSMD050-60V | C70113 | 1812 | Polymeric PTC Resettable Fuse 60V 500mA Surface Mount 1812 |  | 0.0649 | 5.47 | 183050 | 9.00 | Доступно юр.лицам |  | 0 | 5.47 | LCSC (Китай) по курсу ЦБ | 2735.00 | LCSC: https://www.lcsc.com/product-detail/C70113.html ЧипДип: https://www.chipdip.ru/product/msmd050-60v-sea-land-8052710276 efind: https://efind.ru/offer/mSMD050-60V?stock=1&c=rur&r=0&hp=0&opriv=0
3 | D1, D3 | 2 | 1000 | SS36 | MDD(Microdiode Semiconductor) | SS36 | C16015 | SMA(DO-214AC) | Diode Independent 60V 3A Surface Mount SMA(DO-214AC) | защита от переполюсовки, 60 В: при −30 В звон кабеля даёт 43 В | 0.0276 | 2.33 | 502340 | 4.10 | 5860 шт. | 1.76 | 64 | 1.76 | efind, склад РФ | 1760.00 | LCSC: https://www.lcsc.com/product-detail/C16015.html ЧипДип: https://www.chipdip.ru/product/ss36-diod-shottki-3a-60vt-do-214ab-smc-hottech-9001108552 efind: https://efind.ru/offer/SS36?stock=1&c=rur&r=0&hp=1&opriv=0
4 | D2 | 1 | 500 | SMBJ33A | Jingdao Microelectronics | SMBJ33A | C353366 | SMB | 53.3VC Clamp 11.3A@10/1000us Ipp TVS DIODE SMB | TVS однонаправленный | 0.0289 | 2.44 | 80390 | 5.30 | 2730 шт. | 1.90 | 52 | 1.90 | efind, склад РФ | 950.00 | LCSC: https://www.lcsc.com/product-detail/C353366.html ЧипДип: https://www.chipdip.ru/product/smbj33a-diod-zaschitnyy-odnonapravlennyy-600vt-33v-smb-evvo-9001728939 efind: https://efind.ru/offer/SMBJ33A?stock=1&c=rur&r=0&hp=1&opriv=0
5 | C1 | 1 | 500 | 47uF/50V | DMBJ | RVT1H470M0607 | C970679 | SMD,D6.3xL7.7mm | 47uF ±20% 50V Aluminum Electrolytic Capacitors 2800hrs@105℃ | типовая позиция — подойдёт любой производитель с теми же параметрами; гасит звон при горячем подключении | 0.0296 | 2.50 | 51060 |  |  |  |  | 2.50 | LCSC (Китай) по курсу ЦБ | 1250.00 | LCSC: https://www.lcsc.com/product-detail/C970679.html
6 | C2, C3 | 2 | 1000 | 4.7uF | FH | 1206B475K500NT | C29823 | 1206 | 4.7uF ±10% 50V Ceramic Capacitor X7R 1206 | типовая позиция — подойдёт любой производитель с теми же параметрами | 0.1099 | 9.27 | 392000 |  |  |  |  | 9.27 | LCSC (Китай) по курсу ЦБ | 9270.00 | LCSC: https://www.lcsc.com/product-detail/C29823.html
7 | R6, R19, R21 | 3 | 1500 | 100k | UNI-ROYAL | 0603WAF1003T5E | C25803 | 0603 | 100kΩ ±1% 100mW 0603 Thick Film Resistor | типовая позиция — подойдёт любой производитель с теми же параметрами; датчик пропадания 12 В → АЦП MCU | 0.0032 | 0.27 | 17238500 |  |  |  |  | 0.27 | LCSC (Китай) по курсу ЦБ | 405.00 | LCSC: https://www.lcsc.com/product-detail/C25803.html
8 | R5, R7, R10, R13, R16, R22, R29 | 7 | 3500 | 10k | UNI-ROYAL | 0603WAF1002T5E | C25804 | 0603 | 10kΩ ±1% 100mW 0603 Thick Film Resistor | типовая позиция — подойдёт любой производитель с теми же параметрами; FRAM не выбрана, пока MCU в сбросе; VDD_EXT 1.8 В → АЦП MCU: модем включён | 0.0023 | 0.19 | 591900 |  |  |  |  | 0.19 | LCSC (Китай) по курсу ЦБ | 665.00 | LCSC: https://www.lcsc.com/product-detail/C25804.html
9 | C4, C5, C11, C18, C19, C20, C21, C22, C23, C24, C30, C34, C35 | 13 | 6500 | 100nF | YAGEO | CC0603KRX7R9BB104 | C14663 | 0603 | 100nF ±10% 50V Ceramic Capacitor X7R 0603 | типовая позиция — подойдёт любой производитель с теми же параметрами; VCCA транслятора; VCCB транслятора; у вывода VDD; у вывода VIN | 0.0060 | 0.51 | 5140650 |  |  |  |  | 0.51 | LCSC (Китай) по курсу ЦБ | 3315.00 | LCSC: https://www.lcsc.com/product-detail/C14663.html
10 | U1 | 1 | 500 | LMR16020 | TI | LMR16020PDDAR | C190006 | SOIC-8-EP | Buck Switching Regulator IC Adjustable 0.8V~50V 1 Output 2A SOIC-8-EP | 60 В, 2 А; 600 кГц | 0.4646 | 39.18 | 32556 | 59.57 |  | 43.07 | 9 | 43.07 | efind, склад РФ | 21535.00 | LCSC: https://www.lcsc.com/product-detail/C190006.html ЧипДип: https://www.chipdip.ru/product/lmr16020pddar-ic-pmic-dc-dc-texas-instruments-8030573043 efind: https://efind.ru/offer/LMR16020PDDAR?stock=1&c=rur&r=0&hp=1&opriv=0
11 | R1 | 1 | 500 | 270k | UNI-ROYAL | 0603WAF2703T5E | C22965 | 0603 | 270kΩ ±1% 100mW 0603 Thick Film Resistor | типовая позиция — подойдёт любой производитель с теми же параметрами; включение 7.5 В, выключение 6.5 В | 0.0020 | 0.17 | 338300 |  |  |  |  | 0.17 | LCSC (Китай) по курсу ЦБ | 85.00 | LCSC: https://www.lcsc.com/product-detail/C22965.html
12 | R2 | 1 | 500 | 49.9k | UNI-ROYAL | 0603WAF4992T5E | C23184 | 0603 | 49.9kΩ ±1% 100mW 0603 Thick Film Resistor | типовая позиция — подойдёт любой производитель с теми же параметрами | 0.0032 | 0.27 | 1753900 |  |  |  |  | 0.27 | LCSC (Китай) по курсу ЦБ | 135.00 | LCSC: https://www.lcsc.com/product-detail/C23184.html
13 | R3, R4 | 2 | 1000 | 41.2k | UNI-ROYAL | 0603WAF4122T5E | C23166 | 0603 | 41.2kΩ ±1% 100mW 0603 Thick Film Resistor | типовая позиция — подойдёт любой производитель с теми же параметрами; 600 кГц; VBAT = 0.75 × (1 + 41.2/10) = 3.84 В | 0.0017 | 0.14 | 12780 |  |  |  |  | 0.14 | LCSC (Китай) по курсу ЦБ | 140.00 | LCSC: https://www.lcsc.com/product-detail/C23166.html
14 | L1 | 1 | 500 | 10uH | Sunltech | SLO0630H100MTT | C207842 | SMD,7.3x6.6mm | 4A 10uH ±20% 5.5A 66mΩ Magnetic Shielded Inductor SMD,7.3x6.6mm Fixed Inductors | типовая позиция — подойдёт любой производитель с теми же параметрами; 10 мкГн, насыщение 5.5 А | 0.0834 | 7.03 | 16805 |  |  |  |  | 7.03 | LCSC (Китай) по курсу ЦБ | 3515.00 | LCSC: https://www.lcsc.com/product-detail/C207842.html
15 | C6, C7, C10 | 3 | 1500 | 22uF | Samsung Electro-Mechanics | CL31B226KPHNNNE | C87996 | 1206 | 22uF ±10% 10V Ceramic Capacitor X7R 1206 | типовая позиция — подойдёт любой производитель с теми же параметрами; у выводов VBAT модема | 0.1022 | 8.62 | 242145 |  |  |  |  | 8.62 | LCSC (Китай) по курсу ЦБ | 12930.00 | LCSC: https://www.lcsc.com/product-detail/C87996.html
16 | C8, C9, C14, C33 | 4 | 2000 | 470uF/6.3V | JIERR | MA6.3V470M6X8 | C54321567 | SMD,D6.3xL7.7mm | 470uF 6.3V 3.8A@100kHz 20mΩ@100kHz ±20% SMD,D6.3xL7.7mm Aluminum - Polymer Capacitors RoHS | типовая позиция — подойдёт любой производитель с теми же параметрами; запас MCU > 30 мс; полимер 20 мОм; C8+C9 = 940 мкФ; у модема; вместе с C8/C9 — 1410 мкФ под минимум VBAT 3.4 В | 0.0920 | 7.76 | 20155 |  |  |  |  | 7.76 | LCSC (Китай) по курсу ЦБ | 15520.00 | LCSC: https://www.lcsc.com/product-detail/C54321567.html
17 | D4 | 1 | 500 | SMAZ5V1 | DIODES | SMAZ5V1-13-F | C154748 | SMA | Zener Diode Independent 5.1V 1W Surface Mount SMA | по руководству Air780E: стабилитрон 5.1 В 1 Вт у VBAT | 0.1028 | 8.67 | 16740 | 21.19 |  | 14.56 | 2 | 14.56 | efind, склад РФ | 7280.00 | LCSC: https://www.lcsc.com/product-detail/C154748.html ЧипДип: https://www.chipdip.ru/product/smaz5v1-13-f-diod-stabilitron-1vt-5-1v-196ma-sma-diodes-8017545099 efind: https://efind.ru/offer/SMAZ5V1?stock=1&c=rur&r=0&hp=1&opriv=0
18 | D5 | 1 | 500 | BAT54WS | FUXINSEMI | BAT54WS | C3040452 | SOD-323(SC-90) | Diode 30V 200mA Surface Mount SOD-323(SC-90) | отделяет MCU от просадок модема и пропадания питания | 0.0103 | 0.87 | 122950 | 1.70 | 7833 шт. | 0.05 | 66 | 1.70 | ЧипДип | 850.00 | LCSC: https://www.lcsc.com/product-detail/C3040452.html ЧипДип: https://www.chipdip.ru/product/bat54ws-diod-shottki-0.2a-30v-sod-323-hottech-9001276135 efind: https://efind.ru/offer/BAT54WS?stock=1&c=rur&r=0&hp=1&opriv=0
19 | C15, C16 | 2 | 1000 | 1uF | Samsung Electro-Mechanics | CL10A105KB8NNNC | C15849 | 0603 | 1uF ±10% 50V Ceramic Capacitor X5R 0603 | типовая позиция — подойдёт любой производитель с теми же параметрами | 0.0088 | 0.74 | 0 |  |  |  |  | 0.74 | LCSC (Китай) по курсу ЦБ | 740.00 | LCSC: https://www.lcsc.com/product-detail/C15849.html
20 | U2 | 1 | 500 | ME6211C33 | MICRONE | ME6211C33M5G-N | C82942 | SOT-23-5 | 3.3V Positive Fixed SOT-23-5 Voltage Regulators - Linear, Low Drop Out (LDO) Regulators RoHS |  | 0.0431 | 3.63 | 243440 | 4.20 | 4475 шт. | 2.23 | 12 | 2.23 | efind, склад РФ | 1115.00 | LCSC: https://www.lcsc.com/product-detail/C82942.html ЧипДип: https://www.chipdip.ru/product/me6211c33m5g-n-stabilizator-napryazheniya-uvh-do-6v-microne-9000660061 efind: https://efind.ru/offer/ME6211C33M5G?stock=1&c=rur&r=0&hp=1&opriv=0
21 | U3 | 1 | 500 | STM32G030K8T6 | ST | STM32G030K8T6TR | C724044 | LQFP-32(7x7) | ARM Cortex-M0+ 32 Bit 64MHz LQFP-32(7x7) Microcontrollers RoHS |  | 1.1489 | 96.89 | 1579 | 99.00 | 1944 шт. | 1.52 | 18 | 99.00 | ЧипДип | 49500.00 | LCSC: https://www.lcsc.com/product-detail/C724044.html ЧипДип: https://www.chipdip.ru/product/stm32g030k8t6-mikrokontroller-arm-st-microelectronics-9001570285 efind: https://efind.ru/offer/STM32G030K8T6?stock=1&c=rur&r=0&hp=1&opriv=0
22 | C17 | 1 | 500 | 10uF | Samsung Electro-Mechanics | CL21A106KAYNNNE | C15850 | 0805 | 10uF ±10% 25V Ceramic Capacitor X5R 0805 | типовая позиция — подойдёт любой производитель с теми же параметрами | 0.0671 | 5.66 | 2261560 |  |  |  |  | 5.66 | LCSC (Китай) по курсу ЦБ | 2830.00 | LCSC: https://www.lcsc.com/product-detail/C15850.html
23 | U4 | 1 | 500 | FM25L16B | Infineon/CYPRESS | FM25L16B-GTR | C466849 | SOIC-8 | 16Kbit 20MHz SPI SOIC-8 Memory RoHS | 16 кбит, от 2.7 В | 1.1631 | 98.09 | 14630 | 101.12 |  | 75.15 | 29 | 75.15 | efind, склад РФ | 37575.00 | LCSC: https://www.lcsc.com/product-detail/C466849.html ЧипДип: https://www.chipdip.ru/product/fm25l16b-gtr-so-8-2kx8-infineon-8058150397 efind: https://efind.ru/offer/FM25L16B?stock=1&c=rur&r=0&hp=1&opriv=0
24 | J2 | 1 | 500 | COIN | JST | B2B-XH-A(LF)(SN) | C158012 | Through Hole,P=2.5mm | Connector Header 2 position 2.5mm Pitch 3A Through Hole -25℃~+85℃ | 1 = +12 В акцептора, 2 = импульс | 0.0322 | 2.72 | 433100 | 8.50 | 1474 шт. | 0.06 | 27 | 8.50 | ЧипДип | 4250.00 | LCSC: https://www.lcsc.com/product-detail/C158012.html ЧипДип: https://www.chipdip.ru/product/b2b-xh-a-lf-sn-razem-shtyrevoy-na-platu-2.5-mm-2-jst-9000015961 efind: https://efind.ru/offer/B2B-XH-A?stock=1&c=rur&r=0&hp=1&opriv=0
25 | R11, R14 | 2 | 1000 | 2.2k | UNI-ROYAL | 1206W4F2201T5E | C17948 | 1206 | 2.2kΩ ±1% 250mW 1206 Thick Film Resistor | типовая позиция — подойдёт любой производитель с теми же параметрами; ≈5 мА через светодиод; 1206 на 12 В — 21 % номинала | 0.0066 | 0.56 | 328600 |  |  |  |  | 0.56 | LCSC (Китай) по курсу ЦБ | 560.00 | LCSC: https://www.lcsc.com/product-detail/C17948.html
26 | D6, D7, D8, D9 | 4 | 2000 | 1N4148W | ST(Semtech) | 1N4148W | C81598 | SOD-123 | Diode Independent 75V 150mA Surface Mount SOD-123 | параллельно светодиоду: обратное на светодиоде ≤ 0.7 В; последовательный: при перепутанных +12 В и GND не просаживает линию аппарата | 0.0100 | 0.84 | 2194750 | 1.40 | 19561 шт. | 0.01 | 127 | 1.40 | ЧипДип | 2800.00 | LCSC: https://www.lcsc.com/product-detail/C81598.html ЧипДип: https://www.chipdip.ru/product/1n4148w-diod-impulsnyy-0.15a-100v-sod-123-yj-9001624626 efind: https://efind.ru/offer/1N4148W?stock=1&c=rur&r=0&hp=1&opriv=0
27 | U5, U6 | 2 | 1000 | EL817S1(B) | EVERLIGHT | EL817S1(B)(TU)-F | C63268 | SOP-4-2.54mm | Phototransistor Output 5kVrms 1 Channel SOP-4-2.54mm |  | 0.0308 | 2.60 | 248380 | 3.70 |  | 1.74 | 6 | 1.74 | efind, склад РФ | 1740.00 | LCSC: https://www.lcsc.com/product-detail/C63268.html ЧипДип: https://www.chipdip.ru/product/el817s1-b-tu-f-everlight-8060482831 efind: https://efind.ru/offer/EL817S1%28B%29?stock=1&c=rur&r=0&hp=1&opriv=0
28 | R12, R15 | 2 | 1000 | 4.7k | UNI-ROYAL | 0603WAF4701T5E | C23162 | 0603 | 4.7kΩ ±1% 100mW 0603 Thick Film Resistor | типовая позиция — подойдёт любой производитель с теми же параметрами; подтяжка 4.7 кОм: задержка 2.2 мс | 0.0027 | 0.23 | 17073500 |  |  |  |  | 0.23 | LCSC (Китай) по курсу ЦБ | 230.00 | LCSC: https://www.lcsc.com/product-detail/C23162.html
29 | J3 | 1 | 500 | BILL | JST | B3B-XH-A(LF)(SN) | C144394 | Through Hole,P=2.5mm | Connector Header 3 position 2.5mm Pitch 3A Through Hole -25℃~+85℃ | 1 = +12 В акцептора, 2 = импульс | 0.0400 | 3.37 | 192060 | 9.00 | 3387 шт. | 2.00 | 26 | 2.00 | efind, склад РФ | 1000.00 | LCSC: https://www.lcsc.com/product-detail/C144394.html ЧипДип: https://www.chipdip.ru/product/sct2501wv-03p-b3b-xh-a-vilka-pryamaya-na-platu-scondar-9000546313 efind: https://efind.ru/offer/B3B-XH-A?stock=1&c=rur&r=0&hp=1&opriv=0
30 | U7 | 1 | 500 | EG800K-EU | Quectel | EG800KEULC-I03-SNNSA | C44008839 | SMD,17.7x15.8mm | SMD,17.7x15.8mm RF Transceiver Modules and Modems | модем: на LCSC мало, для партии — дистрибьютор Quectel, давальческая поставка; Quectel, LTE Cat.1 bis, B1/B3/B5/B7/B8/B20/B28; VBAT 3.4–4.3 В, логика 1.8 В | 4.8050 | 405.24 | 32 | 974.00 | Доступно юр.лицам |  | 0 | 405.24 | LCSC (Китай) по курсу ЦБ | 202620.00 | LCSC: https://www.lcsc.com/product-detail/C44008839.html ЧипДип: https://www.chipdip.ru/product/eg800keulc-i03-snnsa-quectel-8061061881 efind: https://efind.ru/offer/EG800K?stock=1&c=rur&r=0&hp=0&opriv=0
31 | C12, C25, C26, C27 | 4 | 2000 | 33pF | FH | 0402CG330J500NT | C1562 | 0402 | 33pF ±5% 50V Ceramic Capacitor C0G 0402 | типовая позиция — подойдёт любой производитель с теми же параметрами | 0.0033 | 0.28 | 719900 |  |  |  |  | 0.28 | LCSC (Китай) по курсу ЦБ | 560.00 | LCSC: https://www.lcsc.com/product-detail/C1562.html
32 | C13 | 1 | 500 | 10pF | Samsung Electro-Mechanics | CL05C100JB5NNNC | C32949 | 0402 | 10pF ±5% 50V Ceramic Capacitor C0G 0402 | типовая позиция — подойдёт любой производитель с теми же параметрами | 0.0052 | 0.44 | 450100 |  |  |  |  | 0.44 | LCSC (Китай) по курсу ЦБ | 220.00 | LCSC: https://www.lcsc.com/product-detail/C32949.html
33 | C31 | 1 | 500 | 3.9pF | FH | 0402CG3R9C500NT | C1566 | 0402 | 3.9pF 50V Ceramic Capacitor C0G 0402 | типовая позиция — подойдёт любой производитель с теми же параметрами | 0.0030 | 0.25 | 267800 |  |  |  |  | 0.25 | LCSC (Китай) по курсу ЦБ | 125.00 | LCSC: https://www.lcsc.com/product-detail/C1566.html
34 | C32 | 1 | 500 | 1.8pF | FH | 0402CG1R8C500NT | C1553 | 0402 | 1.8pF 50V Ceramic Capacitor C0G 0402 | типовая позиция — подойдёт любой производитель с теми же параметрами | 0.0053 | 0.45 | 150800 |  |  |  |  | 0.45 | LCSC (Китай) по курсу ЦБ | 225.00 | LCSC: https://www.lcsc.com/product-detail/C1553.html
35 | U9 | 1 | 500 | TXS0102 | TI | TXS0102DCUR | C53434 | VSSOP-8 | 24Mbps 1 2 VSSOP-8 Translators, Level Shifters RoHS | A1=MODEM_RXD↔B1=MCU_TX, A2=MODEM_TXD↔B2=MCU_RX; OE от VDD_EXT | 0.1357 | 11.44 | 45930 | 27.00 | 562 шт. | 0.17 | 23 | 27.00 | ЧипДип | 13500.00 | LCSC: https://www.lcsc.com/product-detail/C53434.html ЧипДип: https://www.chipdip.ru/product/txs0102dcur-preobrazovatel-logicheskogo-texas-instruments-9000165762 efind: https://efind.ru/offer/TXS0102DCUR?stock=1&c=rur&r=0&hp=1&opriv=0
36 | Q1, Q2 | 2 | 1000 | 2N7002 | JSCJ | 2N7002 | C8545 | SOT-23 | N-Channel 60V 115mA 0.225W Surface Mount SOT-23 | PWRKEY > 1 с — включение; RESET_N > 100 мс; после сброса модем выключен — включать через PWRKEY | 0.0129 | 1.09 | 1440400 | 1.50 | 20767 шт. | 0.01 | 115 | 1.50 | ЧипДип | 1500.00 | LCSC: https://www.lcsc.com/product-detail/C8545.html ЧипДип: https://www.chipdip.ru/product/2n7002-tranzistor-n-mosfet-60v-0.115a-0.225vt-2om-kuu-9001205699 efind: https://efind.ru/offer/2N7002?stock=1&c=rur&r=0&hp=1&opriv=0
37 | R18, R20, R27, R28 | 4 | 2000 | 1k | UNI-ROYAL | 0603WAF1001T5E | C21190 | 0603 | 1kΩ ±1% 100mW 0603 Thick Film Resistor | типовая позиция — подойдёт любой производитель с теми же параметрами | 0.0026 | 0.22 | 7735100 |  |  |  |  | 0.22 | LCSC (Китай) по курсу ЦБ | 440.00 | LCSC: https://www.lcsc.com/product-detail/C21190.html
38 | J4 | 1 | 500 | NANO SIM | SHOU HAN | NANO SIM XG6P H1.35 | C7529386 | SMD | Card Connector NANO SIM Hinged Lid Surface Mount | типовая позиция — подойдёт любой производитель с теми же параметрами; откидная крышка — карта не выпадет от вибрации | 0.1016 | 8.57 | 33275 |  |  |  |  | 8.57 | LCSC (Китай) по курсу ЦБ | 4285.00 | LCSC: https://www.lcsc.com/product-detail/C7529386.html
39 | R23, R24, R25 | 3 | 1500 | 22Ω | UNI-ROYAL | 0603WAF220JT5E | C23345 | 0603 | 22Ω ±1% 100mW 0603 Thick Film Resistor | типовая позиция — подойдёт любой производитель с теми же параметрами | 0.0015 | 0.13 | 5225000 |  |  |  |  | 0.13 | LCSC (Китай) по курсу ЦБ | 195.00 | LCSC: https://www.lcsc.com/product-detail/C23345.html
40 | R30 | 1 | 500 | 15k | UNI-ROYAL | 0603WAF1502T5E | C22809 | 0603 | 15kΩ ±1% 100mW 0603 Thick Film Resistor | типовая позиция — подойдёт любой производитель с теми же параметрами; подтяжка данных SIM по Hardware Design EG800K, рис. 17 | 0.0030 | 0.25 | 4013500 |  |  |  |  | 0.25 | LCSC (Китай) по курсу ЦБ | 125.00 | LCSC: https://www.lcsc.com/product-detail/C22809.html
41 | U8 | 1 | 500 | SRV05-4 | MSKSEMI | SRV05-4 | C2836319 | SOT-23-6 | 12VC Clamp 4.5A@8/20us Ipp ESD DIODE SOT-23-6 | ESD у держателя, 0.6 пФ | 0.0235 | 1.98 | 481040 | 2.80 | 705 шт. | 0.95 | 68 | 2.80 | ЧипДип | 1400.00 | LCSC: https://www.lcsc.com/product-detail/C2836319.html ЧипДип: https://www.chipdip.ru/product/srv05-4-diodnaya-sborka-dlya-zaschity-vysokoskorostnyh-kuu-9001291670 efind: https://efind.ru/offer/SRV05-4?stock=1&c=rur&r=0&hp=1&opriv=0
42 | R26 | 1 | 500 | 0Ω | UNI-ROYAL | 0402WGF0000TCE | C17168 | 0402 | 0Ω ±1% 62.5mW 0402 Thick Film Resistor | типовая позиция — подойдёт любой производитель с теми же параметрами; П-цепь согласования: подбирается с антенной | 0.0026 | 0.22 | 6274200 |  |  |  |  | 0.22 | LCSC (Китай) по курсу ЦБ | 110.00 | LCSC: https://www.lcsc.com/product-detail/C17168.html
43 | J5 | 1 | 500 | U.FL | HRS | U.FL-R-SMT-1(80) | C88374 | SMD | Connector Receptacle IPEX Male Pin 50Ω Surface Mount | пигтейл на SMA в стенке корпуса | 0.0678 | 5.72 | 143545 |  |  | 0.01 | 57 | 5.72 | LCSC (Китай) по курсу ЦБ | 2860.00 | LCSC: https://www.lcsc.com/product-detail/C88374.html efind: https://efind.ru/offer/U.FL-R-SMT-1?stock=1&c=rur&r=0&hp=1&opriv=0
44 | D10 | 1 | 500 | зелёный | NATIONSTAR | NCD0805G1 | C84260 | 0805 | Green 520nm LED Indication - Discrete 2.5V~3.6V 0805 | типовая позиция — подойдёт любой производитель с теми же параметрами; LED1: мигает на каждый принятый импульс | 0.0184 | 1.55 | 729720 |  |  |  |  | 1.55 | LCSC (Китай) по курсу ЦБ | 775.00 | LCSC: https://www.lcsc.com/product-detail/C84260.html
45 | D11 | 1 | 500 | красный | NATIONSTAR | NCD0805R1 | C84256 | 0805 | Red 630nm LED Indication - Discrete 1.6V~2.6V 0805 | типовая позиция — подойдёт любой производитель с теми же параметрами; LED2: сеть и последняя выгрузка | 0.0106 | 0.89 | 4881950 |  |  |  |  | 0.89 | LCSC (Китай) по курсу ЦБ | 445.00 | LCSC: https://www.lcsc.com/product-detail/C84256.html
46 | SW1 | 1 | 500 | ВЫГРУЗКА | XKB Connection | TS-1187A-B-A-B | C318884 | SMD-4P,5.1x5.1mm | Tactile Switch SPST 160gf 1.5mm 5.1mm x 5.1mm Surface Mount | подключены площадки по диагонали — всегда разные контакты кнопки | 0.0160 | 1.35 | 564360 | 1.00 | Доступно юр.лицам |  | 0 | 1.35 | LCSC (Китай) по курсу ЦБ | 675.00 | LCSC: https://www.lcsc.com/product-detail/C318884.html ЧипДип: https://www.chipdip.ru/product/ts1187a16015-hanelec-8057143746 efind: https://efind.ru/offer/TS-1187A?stock=1&c=rur&r=0&hp=0&opriv=0

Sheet: Итого
ИМ-01 — перечень комплектующих
Дата | 2026-09-15
Курс ЦБ, ₽ за $ | 84.3363 на 2026-09-15
Количество плат | 500
Позиций в перечне | 46
Деталей на одну плату | 90
Комплектующие на 1 плату, ₽ (лучшая цена: РФ, если хватает на партию, иначе LCSC) | 842.48
Комплектующие на 500 плат, ₽ | 421240
Для сравнения: всё с LCSC, ₽ на 1 плату (без доставки и пошлин) | 824.5
Не входит в сумму | печатная плата, монтаж, корпус, антенна с пигтейлом, Y-жгуты, SIM и тариф, доставка и таможня для позиций из Китая
Как считались цены в РФ | ЧипДип — цена за штуку для нужного количества по шкале скидок, только если на складе хватает на всю партию; efind.ru — лучшая цена по шкале скидок среди предложений с наличием (efind не даёт надёжно спарсить точное число штук на складе у каждого поставщика — проверяйте по ссылке перед заказом)
Внимание | у поставщиков из efind бывают ограничения: минимальная сумма заказа, только юрлица, требуется уточнение наличия на нужное количество — смотрите по ссылке в перечне перед заказом

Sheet: Не монтируются
Обозначение | Что это | Почему нет в перечне
C28 | 10pF C_0402_1005Metric | место под согласование антенны, по умолчанию пусто
C29 | 10pF C_0402_1005Metric | место под согласование антенны, по умолчанию пусто
J6 | SWD | контрольная точка / отверстие / площадки программатора — только на плате
TP1 | VIN | контрольная точка / отверстие / площадки программатора — только на плате
TP2 | VBAT | контрольная точка / отверстие / площадки программатора — только на плате
TP3 | +3V3 | контрольная точка / отверстие / площадки программатора — только на плате
TP4 | GND | контрольная точка / отверстие / площадки программатора — только на плате
TP5 | MCU_DBG_TX | контрольная точка / отверстие / площадки программатора — только на плате
TP6 | MCU_DBG_RX | контрольная точка / отверстие / площадки программатора — только на плате
TP7 | MODEM_DBG_TX | контрольная точка / отверстие / площадки программатора — только на плате
TP8 | MODEM_DBG_RX | контрольная точка / отверстие / площадки программатора — только на плате
TP9 | USB_DP | контрольная точка / отверстие / площадки программатора — только на плате
TP10 | USB_DN | контрольная точка / отверстие / площадки программатора — только на плате
TP11 | VBUS | контрольная точка / отверстие / площадки программатора — только на плате
TP12 | USB_BOOT | контрольная точка / отверстие / площадки программатора — только на плате
TP13 | NET_STATUS | контрольная точка / отверстие / площадки программатора — только на плате
H1 | M3 | контрольная точка / отверстие / площадки программатора — только на плате
H2 | M3 | контрольная точка / отверстие / площадки программатора — только на плате
H3 | M3 | контрольная точка / отверстие / площадки программатора — только на плате
H4 | M3 | контрольная точка / отверстие / площадки программатора — только на плате

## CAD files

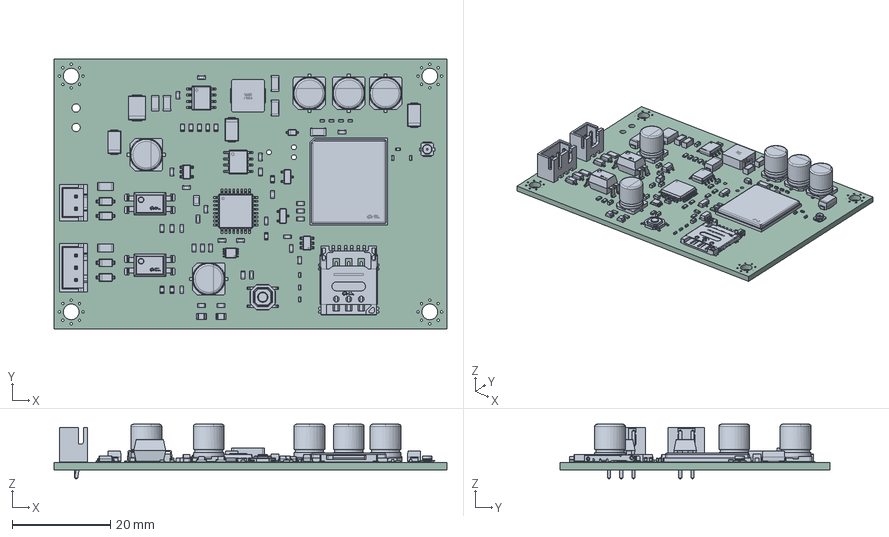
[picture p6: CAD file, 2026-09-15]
hardware/fab/im01.step
80.0 x 55.0 x 11.1 mm
R_0603_1608Metric x 24
C_0402_1005Metric x 9
JST_XH_B2B-XH-A_1x02_P2.50mm_Vertical
C_0603_1608Metric x 15
LGA-109_L17.7-W15.8-AIR780E
U.FL_Hirose_U.FL-R-SMT-1_Vertical
D_SOD-123 x 4
IND-SMD_L7.1-W6.6-H2.8
SW-SMD_4P-L5.1-W5.1-P3.70-LS6.5-TL_H1.5
SOT-23 x 2
D_SMA x 3
SOP-4_L6.5-W4.6-H4.5-P2.54-LS10.2-TL x 2
CP_Elec_6.3x7.7 x 5
C_1206_3216Metric x 5
SOIC-8_L4.9-W3.9-P1.27-LS6.0-BL-EP
LQFP-32_7x7mm_P0.8mm
SIM-SMD_NANO-SIM-XG6P-H1.35
JST_XH_B3B-XH-A_1x03_P2.50mm_Vertical
VSSOP-8_2.3x2mm_P0.5mm
SOIC-8_3.9x4.9mm_P1.27mm
R_1206_3216Metric x 2
LED_0805_2012Metric x 2
SOT-23-5
D_SMB
C_0805_2012Metric
SOT-23-6
D_SOD-323
R_0402_1005Metric
im01_PCB

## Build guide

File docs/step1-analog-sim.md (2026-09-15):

# ИМ-01, шаг 1 — аналоговая симуляция: результаты и поправки к спецификации

Дата: 15.09.2026. Симулятор: ngspice 42. Как повторить: `python3 sim/run_sim.py` —
пересобирает все цифры в [`sim/results_auto.md`](../sim/results_auto.md) и графики в `sim/out/`.

## Коротко, без схемотехники

Схема в целом рабочая: импульсы проходят чисто, помехи отсекаются, 1000 мкФ на питании модема
в большинстве случаев хватает. Нашлись четыре вещи, которые надо поправить до разводки платы:

1. **Преобразователь питания выбран не того класса.** Спецификация обещает вход 9–30 В, а MP1584
   по даташиту работает только до 28 В. При горячем подключении 30 В на его входе бывает 41 В.
   Нужен преобразователь на 60 В (класс LMR16020). Это дороже на десятки рублей, лимит 1709 ₽
   не под угрозой.
2. **Одна ошибка монтажа может сломать работу аппарата.** Если на разъёме устройства перепутать
   «+12 В» и «землю», наш вход просаживает линию импульсов аппарата с 12 до 2.6 В — аппарат может
   принять это за бесконечный импульс. Решение 2 из §3 («не может нарушить работу аппарата») это
   нарушает. Лечится ещё одним диодом за 1 ₽.
3. **Запас питания при отключении света меньше обещанного.** Когда модем простаивает, после
   пропадания 12 В устройство живёт 17 мс. Во время передачи — только 3.3 мс, впритык ко времени,
   за которое импульс проходит фильтр. Нужны датчик пропадания 12 В и ключ, отключающий модем
   (он же пригодится для аварийной перезагрузки модема) — тогда запас больше 70 мс.
4. **Порог 10 мс в прошивке стоит на краю.** Фильтр входа растягивает или сжимает импульс на
   0.8–1.5 мс, поэтому помеха в 9 мс может пройти как 10 мс. Предлагаю порог 15 мс — это всё ещё
   намного меньше самого короткого настоящего импульса (25 мс).

Пункты 1–3 — инженерные решения внутри §4–§5, пункт 4 меняет требование §7, по нему нужно ваше
согласие.

## Критерии приёмки шага 1 (IM-01 §9)

| Критерий | Итог |
| --- | --- |
| Задержка фильтра < 3 мс, оба режима NO/NC | проходит: 2.82 мс при номинале §4, **2.19 мс с подтяжкой 4.7 кОм** |
| Спайк 0.2 мс не доходит до логического порога, NO и NC | проходит во всех вариантах, включая деградацию оптопары до CTR 20 % |
| VBAT не опускается ниже минимума модуля (3.3 В по Hardware Design Manual Air780E) | проходит при 1000 мкФ во всех профилях нагрузки, если частота среза петли ≥ 1 кГц; на 0.5 кГц — 3.34 В, запас 40 мВ |
| Ни один элемент не выходит за предельные режимы | **проходит только с поправками ниже**: преобразователь на 60 В, диод Шоттки на 60 В, резистор светодиода 1206 |

## 1. Входной каскад (§4)

Модель: открытый коллектор акцептора, штатная подтяжка контроллера аппарата 10 кОм к 12 В,
оптопара PC817-класса, фильтр 10 кОм + 100 нФ, пороги входа MCU худшего случая STM32
(низкий ≤ 0.3·VDD, высокий ≥ 0.7·VDD).

| Подтяжка / CTR | Задержка, худший фронт | Спайк 0.2 мс: NO / NC | Искажение длительности импульса |
| --- | --- | --- | --- |
| 10 кОм / 50 % (номинал §4) | 2.82 мс | 2.18 В / 0.17 В | NO +1.5 мс, NC −1.5 мс |
| 10 кОм / 20 % | 2.81 мс | 2.60 В / 0.21 В | ±1.35 мс |
| **4.7 кОм / 50 %** | **2.19 мс** | 2.31 В / 0.23 В | **±0.8 мс** |
| 4.7 кОм / 20 % | 2.17 мс | 2.89 В / 0.32 В | ±0.5 мс |
| 10 кОм / 50 %, VDD 1.8 В | 2.78 мс | 1.18 В / 0.12 В | ±1.45 мс |

Нагрузка на линию акцептора: 4.9 мА через светодиод, вместе со штатной подтяжкой 6.1 мА —
десятки миллиампер открытого коллектора с запасом. В режиме NC светодиод горит постоянно.

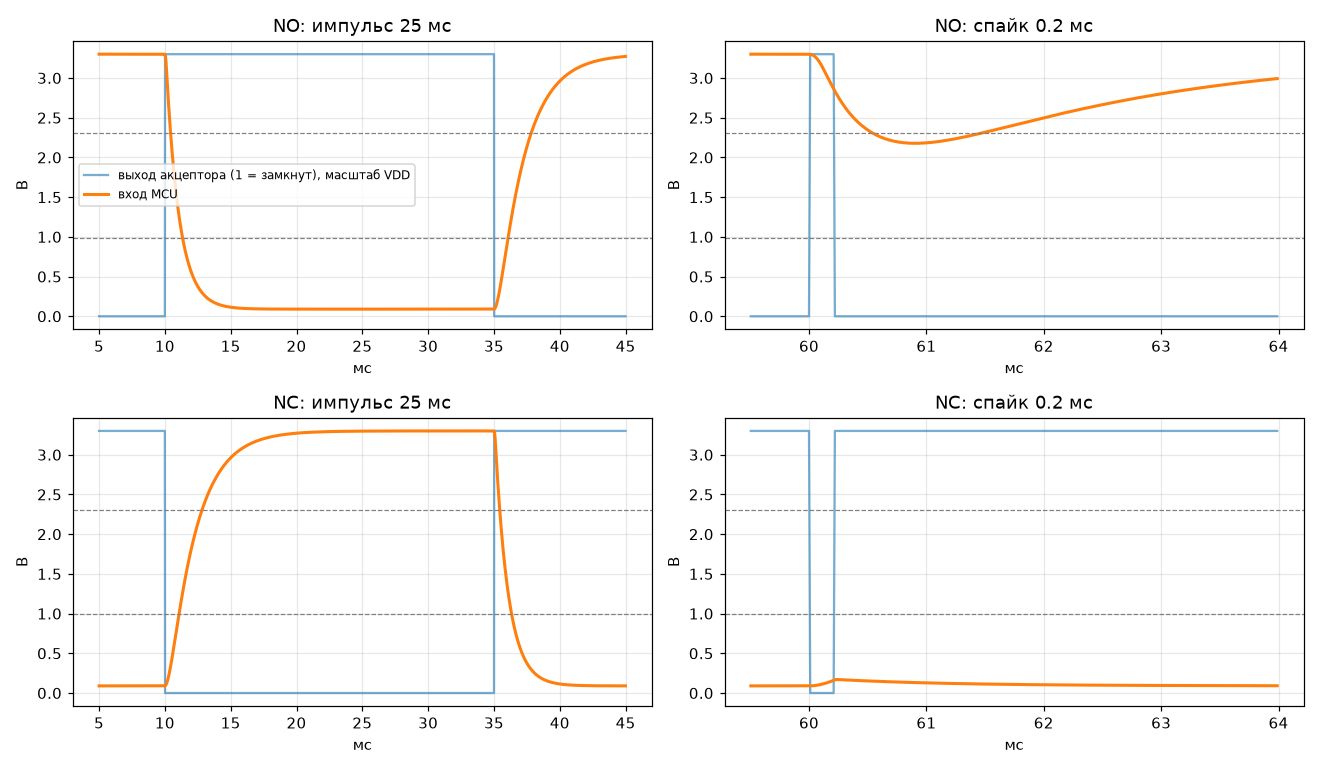
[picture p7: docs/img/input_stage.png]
Входной каскад


Что видно на графике: после спайка вход MCU продолжает проседать ещё около 0.2 мс — это время
рассасывания заряда в насыщенном фототранзисторе. Чем выше CTR, тем глубже насыщение и тем
заметнее эффект. Реальную величину даст осциллограф на пилоте.

**Поправки:**

- **Подтяжка выхода оптопары — 4.7 кОм вместо 10 кОм.** Задержка падает с 2.82 до 2.19 мс
  (запас до 3 мс вырастает вдвое), искажение длительности — с ±1.5 до ±0.8 мс, фототранзистор
  меньше насыщается. Ток через подтяжку 0.7 мА, даже при CTR 20 % оптопара открывается полностью.
- **Последовательный диод в цепи светодиода** (LL4148/1N4148) в дополнение к обратному
  параллельному. Параллельный остаётся обязательным, как в §4: он держит обратное напряжение на
  светодиоде около 0.6 В. Последовательный нужен против ошибки монтажа C1 ниже. Ток светодиода
  падает с 4.93 до 4.63 мА — несущественно.
- **Резистор 2.2 кОм — типоразмер 1206** (0.25 Вт): на 12 В рассеивается 53 мВт, 21 % номинала.
  На линии 24 В было бы 235 мВт — 94 % номинала 1206; если такие аппараты встретятся, ставить два
  1206 по 1.1 кОм последовательно.

### Ошибки монтажа

| Случай | Что происходит |
| --- | --- |
| Перепутаны «+12 В» и «импульс», параллельный диод есть | светодиод под 0.66 В обратного — цел; линия аппарата не нагружена; импульсы не видны, LED1 не мигает — ошибка обнаруживается на монтаже |
| То же без параллельного диода | 12.6 В обратного при пределе PC817 6 В — светодиод погибает. Требование §4 подтверждено |
| C1: перепутаны «+12 В» и GND, только параллельный диод | **линия импульсов аппарата в покое проседает с 12 до 2.64 В** — ток течёт от штатной подтяжки аппарата через обратный диод |
| C2: то же, с последовательным диодом | линия 12.0 В, светодиод цел |

Разъёмы ключёванные (§6), поэтому C1 возможна только при самодельном или неправильно обжатом жгуте,
но диод за 1 ₽ дешевле любого разбирательства с «глючащим» аппаратом.

## 2. Защита входа питания (§5)

Цепочка: кабель 1.5 мкГн → предохранитель → диод Шоттки от переполюсовки → TVS → входные
конденсаторы 10 мкФ керамика + 47 мкФ электролит → преобразователь.

**Противоречие в спецификации.** §5 требует вход 9–30 В и называет MP1584-класс, а у MP1584 рабочий
диапазон 4.5–28 В. Даже без переходных процессов 30 В за пределами его паспорта, а TVS со стоянием
≥ 30 В ограничивает уже на 37–53 В.

| Сценарий | Вариант A: 9–30 В, SMBJ33A, преобразователь на 60 В | Вариант B: только 12 В, SMBJ18A, MP1584 (до 28 В) |
| --- | --- | --- |
| Горячее подключение 12 В | 11.5 В | 11.5 В |
| Горячее подключение 12 В, плавкий предохранитель, без электролита | — | 16.2 В |
| Горячее подключение 30 В | 29.5 В | не применимо |
| Горячее подключение 30 В, плавкий предохранитель, без электролита | **41.2 В**, TVS принял 2.9 А | не применимо |
| Выброс +50 В / 2 Ом / 50 мкс поверх 12 В | 19.1 В — поглотили входные конденсаторы | 19.1 В |
| Стресс +100 В / 10 Ом / 1 мс | 41.4 В, в TVS 46 мДж | 23.5 В, в TVS 73 мДж |
| Постоянные 24 В | 23.7 В, норма | **TVS проводит 2.5 А постоянно — сгорит** |
| Переполюсовка −30 В | на Шоттки **43 В обратного** (звон кабеля) | то же |

**Поправки:**

- **Вариант A.** Широкий вход в §5 выбран намеренно («откуда брать питание, решается на
  монтаже»), значит, менять надо микросхему, а не диапазон: **преобразователь класса 60 В, 2 А**
  (например, TI LMR16020: вход 4.3–60 В, 2 А), **TVS SMBJ33A**. Строка сметы «Преобразователь 2 А +
  защита + 1000 мкФ» подорожает на десятки рублей — цену нужно запросить у поставщика.
- **Диод Шоттки — на 60 В (SS36-класс), не на 40 В.** При переполюсовке −30 В звон кабеля даёт на
  нём 43 В.
- **Электролит на входе обязателен** (47 мкФ / 50 В, ESR ~0.4 Ом): он гасит звон при горячем
  подключении. Без него и с обычным плавким предохранителем пик достигает 41 В.
- Самовосстанавливающийся предохранитель (0.15–1 Ом) дополнительно демпфирует звон — лучше
  плавкого.

Вариант B допустим, только если отказаться от 24 В и отдельного отвода питания.

## 3. Просадка VBAT (§5.2)

Модель — усреднённый преобразователь с токовым управлением. Настоящей компенсации будущей
микросхемы модель не знает, поэтому частота среза петли перебрана от 0.5 до 40 кГц. Важная
деталь: у LMR16020 компенсация **внутренняя**, под 1000 мкФ её не перенастроить, частота среза
падает примерно обратно пропорционально ёмкости выхода. Поэтому реалистичны как раз столбцы
0.5–1 кГц.

Минимум VBAT у выводов модуля, В (ограничение тока 3 А):

| Ёмкость (ESR) | Профиль | 0.5 кГц | 1 кГц | 5 кГц | 15 кГц |
| --- | --- | --- | --- | --- | --- |
| 470 мкФ (40 мОм) | P1: пики 2 А по 577 мкс | 2.87 ✘ | 3.32 | 3.68 | 3.73 |
| 1000 мкФ (25 мОм) | P1 | **3.34** | 3.56 | 3.73 | 3.75 |
| 2200 мкФ (18 мОм) | P1 | 3.58 | 3.68 | 3.75 | 3.76 |
| 1000 мкФ | P2: LTE-подобный, до 1.1 А | 3.58 | 3.69 | 3.77 | 3.78 |
| 1000 мкФ | P3: 2 А непрерывно 20 мс | **3.34** (выброс 4.24) | 3.56 | 3.73 | 3.75 |

Полные таблицы — в `sim/results_auto.md`.

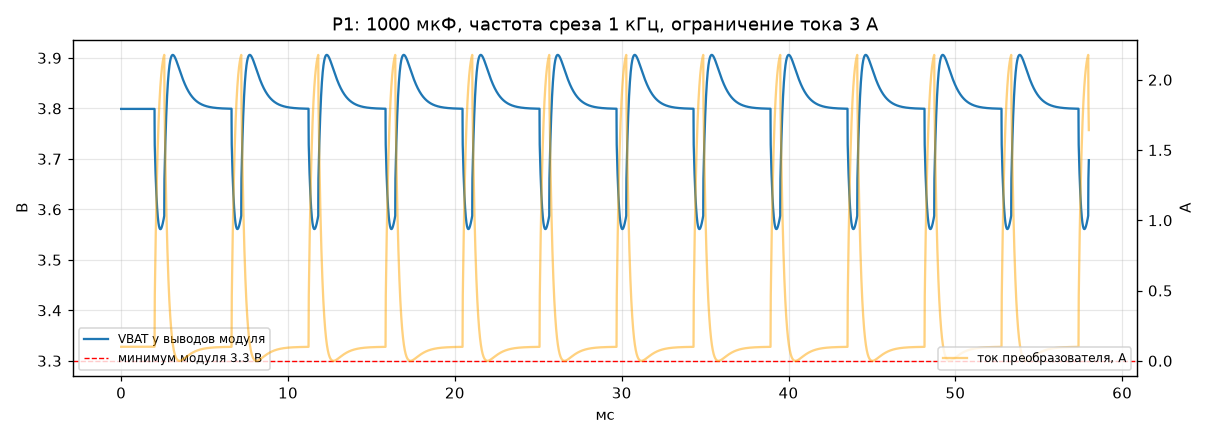
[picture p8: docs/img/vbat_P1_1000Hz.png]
VBAT при медленной петле


**Выводы:**

- **1000 мкФ достаточно, но впритык при медленной петле.** Оценка 5800 мкФ из §5.2 была слишком
  пессимистичной: она предполагала, что петля не реагирует всю пачку, и допуск 0.2 В, тогда как
  реальный допуск от 3.8 до 3.3 В — 0.5 В.
- Профиль P1 (GSM-подобные пачки) — с запасом хуже реального для Cat.1. Для более реалистичного P2
  при 1000 мкФ минимум 3.58 В даже на 0.5 кГц.
- **Поправка:** 1000 мкФ оставить базовым значением, но: (а) у выбранного преобразователя проверить
  по даташиту, допускает ли он такую выходную ёмкость при внутренней компенсации (устойчивость и
  запуск); (б) если реальная частота среза с этой ёмкостью окажется ниже 1 кГц — брать 1500–2200 мкФ;
  (в) на пилоте снять осциллографом просадку при реальной передаче.
- Выброс при сбросе нагрузки на медленной петле доходит до 4.24 В при пределе модуля 4.3 В —
  проверить там же.

## 4. Удержание питания при пропадании 12 В (§2)

§2 утверждает, что ёмкость даёт «десятки миллисекунд», чтобы записать последний импульс.

| Нагрузка | До просадки модема < 3.3 В | До отказа MCU/FRAM (< 2.7 В) |
| --- | --- | --- |
| Модем в ожидании, 100 мА | 12.7 мс | 17.0 мс |
| Модем передаёт, 500 мА | 2.5 мс | **3.3 мс** |
| Передаёт, но модем отключается ключом при входе < 9 В | > 70 мс | > 70 мс |
| Передаёт, вход +100 мкФ | 5.0 мс | 6.0 мс |

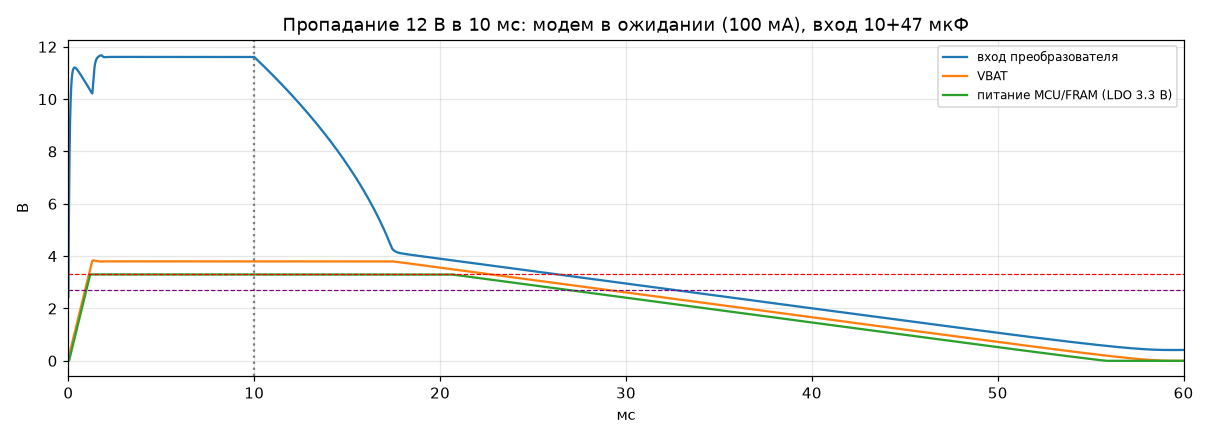
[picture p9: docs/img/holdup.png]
Удержание


Импульс проходит входной фильтр за 2.2–2.8 мс; во время передачи на запись в FRAM остаётся меньше
миллисекунды. Утверждение §2 верно только при простаивающем модеме.

**Поправки:**

- **Датчик пропадания 12 В**: делитель на вход компаратора или АЦП MCU, прерывание при входе
  ниже ~9 В. Около 2 ₽.
- **Ключ питания модема** (P-MOSFET, Rds ≤ 30 мОм — он стоит в цепи бросков 2 А): по прерыванию
  пропадания питания прошивка отключает модем, остаётся ~10 мА на MCU, запас > 70 мс. Тот же ключ
  даёт аппаратный сброс модема для watchdog из §7 п. 5 — сбросить зависший модем по питанию
  надёжнее, чем командой. Около 5–8 ₽.

## 5. Что это меняет в прошивке (§7) — вход для шага 3

- **Считать на заднем фронте, после проверки длительности.** В режиме NC пропадание 12 В гасит
  светодиод, и для MCU это выглядит как начало импульса, который никогда не закончится. Счёт по
  заднему фронту с проверкой длительности такой «импульс» не засчитает.
- **Как совместить «аппаратный счётчик» и «фильтр ≥ 10 мс».** Счётчик таймера в режиме внешнего
  тактирования считает каждый фронт и длительность не проверяет, а цифровой фильтр входа таймера
  работает в микросекундах, а не в миллисекундах. Предложение для шага 3: таймер в режиме захвата
  фронтов с DMA в кольцевой буфер — момент каждого фронта записывается аппаратно, без участия ядра
  (гарантия §2 сохраняется), а прошивка позже разбирает пары фронтов и делит импульсы на принятые
  и отбракованные. Второй таймер как голый счётчик фронтов остаётся контрольной суммой.
- **Порог длительности: 15 мс вместо 10 мс (нужно согласие).** Фильтр искажает длительность на
  ±0.8 мс (подтяжка 4.7 кОм) или ±1.5 мс (10 кОм), знак зависит от режима NO/NC. С порогом 10 мс
  помеха в 9 мс может пройти. Самый короткий настоящий импульс у всех трёх акцепторов — 25 мс,
  после фильтра не короче 24.2 мс, так что 15 мс оставляет запас в обе стороны.

## 6. Часы передачи (§3, решение 7)

Уточнение владельца от 15.09: аппараты включены круглосуточно, покупатели бывают с 8 до 22.
Сбоя счёта передача не вызывает (счёт аппаратный), но окна логично поставить на простой:

- **22:30** — снимок сразу после закрытия, в нём весь день целиком;
- **07:30** — повтор перед открытием, если вечером не удалось;
- каждому устройству — случайный сдвиг 0–10 минут, чтобы 500 модемов не выходили в сеть в одну
  секунду.

Решение 7 требует совпадения с расписанием iVend (DECISION-032: 07:00 и 19:00). В 19:00
покупатели ещё идут, и дневной безнал нельзя будет сравнить с импульсами на одной отсечке. Если
сверять день ко дню, синхронизацию iVend тоже стоит перенести на 22:30 / 07:30. Это изменение
решения из §3 — только с согласия владельца.

## 7. Чего симуляция не показывает — остаётся на пилот (§10)

- реальную длительность, полярность и шум импульсов у TB74, VN-5, EU-9 рядом с соленоидом;
- реальное время выключения PC817 при подтяжке 4.7 кОм;
- реальный профиль тока модема и частоту среза выбранного преобразователя с 1000 мкФ;
- собственный запас питания акцептора: если акцептор успевает выдать импульс после того, как
  отключилось наше устройство, этот импульс пропадёт — это решается датчиком пропадания 12 В и
  сверкой с ручными показаниями.

## Источники цифр из даташитов

- MP1584, вход 4.5–28 В: [MPS, MP1584 Rev. 1.0](https://www.mouser.com/datasheet/2/277/MP1584_r1.0-779241.pdf)
- Air780E, VBAT 3.3–4.3 В, источник питания не менее 1 А: [Air780E Hardware Design Manual](https://fcc.report/FCC-ID/2AEGG-AIR780E/7368233.pdf)
- LMR16020, вход 4.3–60 В, 2 А, внутренняя компенсация: [TI LMR16020](https://www.ti.com/product/LMR16020)
- PC817: обратное напряжение светодиода 6 В — по IM-01 §4.

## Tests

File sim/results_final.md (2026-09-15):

# ИМ-01 — виртуальная модель устройства с окончательными номиналами (сгенерировано run_final.py)

Одна схема ngspice на всё устройство: вход 12 В с защитой (mSMD050, SS36, SMBJ33A, 47 мкФ), LMR16020 (усреднённая модель, ограничение тока 2.5 А — нижняя граница по даташиту), VBAT: 2×22 мкФ + 3×470 мкФ полимер, модем EG800K-EU как нагрузка с пачками передачи, питание MCU через BAT54 и накопитель 470 мкФ, LDO 3.3 В, два оптронных входа (МОНЕТА — NO, КУПЮРА — NC) с подтяжкой 4.7 кОм, датчик 12 В 100к/10к. В момент 150 мс линия 12 В аппарата пропадает посреди передачи.

Критерии: VBAT 3.4–4.3 В (Quectel EG800K); задержка входного фильтра < 3 мс; спайк 0.2 мс не доходит до порога MCU; 3.3 В MCU не проседает при передаче (> 3.2 В); после пропадания 12 В датчик срабатывает, и у MCU остаётся не меньше 3 мс до 2.7 В (минимум FRAM), чтобы дописать счётчики.

| Случай | VBAT мин / макс | 3.3 В MCU мин | Входы: задержки NO / NC | Спайк NO / NC | Датчик 12 В | MCU ≥ 2.7 В после пропадания | Итог |
|---|---|---|---|---|---|---|---|
| LTE-подобная передача, петля 2 кГц, CTR 130 % (EL817 ранг B, минимум) | 3.796 / 3.88 В  | 3.300 В | 1.30–2.20 / 2.20–1.30 мс | 2.21 / 0.19 В | 0.30 мс | 46.85 мс | проходит |
| LTE-подобная передача, петля 2 кГц, CTR 260 % (ранг B, максимум) | 3.796 / 3.88 В  | 3.300 В | 1.27–2.21 / 2.21–1.27 мс | 2.18 / 0.17 В | 0.30 мс | 46.85 мс | проходит |
| LTE-подобная передача, медленная петля 0.5 кГц | 3.699 / 3.96 В  | 3.300 В | 1.30–2.20 / 2.20–1.30 мс | 2.21 / 0.19 В | 0.30 мс | 48.88 мс | проходит |
| Худший случай §5.2: пачки 2 А по 577 мкс, петля 2 кГц | 3.754 / 3.90 В  | 3.300 В | 1.30–2.20 / 2.20–1.30 мс | 2.21 / 0.19 В | 0.30 мс | 48.67 мс | проходит |
| Худший случай §5.2: пачки 2 А по 577 мкс, медленная петля 0.5 кГц | 3.532 / 3.93 В  | 3.300 В | 1.30–2.20 / 2.20–1.30 мс | 2.21 / 0.19 В | 0.30 мс | 50.57 мс | проходит |

✘ — не выполнен критерий по VBAT.

Графики:

- `sim/out/final_0.png`
- `sim/out/final_4.png`

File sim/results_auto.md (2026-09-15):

# ИМ-01, шаг 1 — сводка аналоговой симуляции (сгенерировано run_sim.py)

Симулятор: ngspice-42 : Circuit level simulation program. Файл перезаписывается при каждом прогоне.

## 1. Входной каскад: задержка фильтра и подавление спайка

Пороги входа MCU — худший случай STM32: низкий уровень ≤ 0.3·VDD, высокий ≥ 0.7·VDD.
Задержка — от фронта на выходе акцептора до пересечения худшего порога на входе MCU.

Спайк: критерий §9 — не доходит до порога переключения (NO: остаётся выше 0.3·VDD, NC: ниже 0.7·VDD); строже — вход вообще не выходит из зоны своего уровня.

| Вариант | NO: начало / конец | NC: начало / конец | Спайк 0.2 мс: NO мин. / NC макс. | Уровни | Задержка < 3 мс | Спайк подавлен (§9) | Строже |
|---|---|---|---|---|---|---|---|
| RPU 10 кОм, CTR 50 %, VDD 3.3 В — номинал §4 | 1.33 мс / 2.82 мс | 2.82 мс / 1.33 мс | 2.18 В / 0.17 В | проходит | проходит | проходит | **НЕ проходит** |
| RPU 10 кОм, CTR 20 % — деградация оптопары | 1.47 мс / 2.81 мс | 2.81 мс / 1.47 мс | 2.60 В / 0.21 В | проходит | проходит | проходит | проходит |
| RPU 4.7 кОм, CTR 50 %, VDD 3.3 В | 1.39 мс / 2.19 мс | 2.19 мс / 1.39 мс | 2.31 В / 0.23 В | проходит | проходит | проходит | проходит |
| RPU 4.7 кОм, CTR 20 % — деградация оптопары | 1.67 мс / 2.17 мс | 2.17 мс / 1.67 мс | 2.89 В / 0.32 В | проходит | проходит | проходит | проходит |
| RPU 10 кОм, CTR 50 %, VDD 1.8 В | 1.35 мс / 2.78 мс | 2.78 мс / 1.35 мс | 1.18 В / 0.12 В | проходит | проходит | проходит | **НЕ проходит** |

Длительность импульса, которую увидит прошивка (важно для порога 10 мс из §7):

| Вариант | NO: 10 / 25 / 100 мс | NC: 10 / 25 / 100 мс |
|---|---|---|
| RPU 10 кОм, CTR 50 %, VDD 3.3 В — номинал §4 | 11.49 / 26.49 / 101.49 мс | 8.50 / 23.51 / 98.51 мс |
| RPU 10 кОм, CTR 20 % — деградация оптопары | 11.34 / 26.34 / 101.34 мс | 8.65 / 23.66 / 98.66 мс |
| RPU 4.7 кОм, CTR 50 %, VDD 3.3 В | 10.81 / 25.81 / 100.81 мс | 9.19 / 24.19 / 99.19 мс |
| RPU 4.7 кОм, CTR 20 % — деградация оптопары | 10.50 / 25.50 / 100.51 мс | 9.49 / 24.50 / 99.50 мс |
| RPU 10 кОм, CTR 50 %, VDD 1.8 В | 11.43 / 26.43 / 101.43 мс | 8.56 / 23.57 / 98.57 мс |

Нагрузка на линию акцептора (номинал): ток светодиода 4.93 мА, суммарный ток открытого коллектора (наш канал + штатная подтяжка 10 кОм) 6.12 мА; в режиме NC светодиод горит постоянно, средний ток 4.93 мА; мощность на резисторе 2.2 кОм до 53.40 мВт.

## 2. Ошибки монтажа и 24 В на линии импульса

Предельное обратное напряжение светодиода PC817 — 6 В.

| Случай | Результат |
|---|---|
| Штатно, только диод параллельно светодиоду (§4) | ток светодиода 4.93 мА, линия аппарата в покое 12.00 В |
| Штатно, + последовательный диод | ток светодиода 4.63 мА |
| A: перепутаны «+12 В» и «импульс», диод есть | обратное на светодиоде 0.66 В — проходит; линия аппарата в покое 12.00 В; импульсы не видны (LED1 не мигает — ошибка видна на монтаже) |
| B: то же, диода нет | обратное на светодиоде 12.59 В — **НЕ проходит** |
| C1: перепутаны «+12 В» и GND, только параллельный диод | обратное 0.58 В; **линия аппарата в покое проседает до 2.64 В** (штатно 12.00 В) |
| C2: то же, + последовательный диод | обратное 0.41 В; линия аппарата в покое 12.00 В |
| D: линия 24 В, режим NC | ток светодиода 10.35 мА, мощность на 2.2 кОм 235.49 мВт (0805 — 125 мВт, 1206 — 250 мВт) |

## 3. Защита входа питания

Критерии: пик на входе преобразователя ниже его предела; обратное на диоде Шоттки < 60 В; энергия в TVS < 0.4 Дж и нет постоянного тока через TVS.

### Вариант A — вход 9–30 В: TVS SMBJ33A, преобразователь класса 60 В

Предел по входу преобразователя: 60 В.

| Сценарий | Пик / минимум на входе преобр. | Обратное на Шоттки | Ток TVS макс. | Энергия TVS | Ток TVS в конце | Итог |
|---|---|---|---|---|---|---|
| Горячее подключение 12 В через кабель 1.5 мкГн | 11.5 В / 0.0 В | 0.0 В | 0.00 А | 0.0 мДж | 0.00 мА | проходит |
| Горячее подключение 30 В | 29.5 В / 0.0 В | 0.0 В | 0.00 А | 0.0 мДж | 0.00 мА | проходит |
| Горячее подключение 30 В без входного электролита | 29.7 В / 0.0 В | 0.0 В | 0.00 А | 0.0 мДж | 0.00 мА | проходит |
| Горячее подключение 30 В, самовосст. предохранитель на минимуме 0.15 Ом | 29.6 В / -0.0 В | -0.0 В | 0.00 А | 0.0 мДж | 0.00 мА | проходит |
| Горячее подключение 30 В, плавкий предохранитель 0.05 Ом | 29.6 В / -0.0 В | -0.0 В | 0.00 А | 0.0 мДж | 0.00 мА | проходит |
| Горячее подключение 30 В, плавкий предохранитель, без электролита | 41.2 В / -0.0 В | 20.8 В | 2.86 А | 1.6 мДж | 0.02 мА | проходит |
| Переполюсовка −30 В | 0.0 В / -0.0 В | 43.1 В | 0.00 А | -0.0 мДж | -0.00 мА | проходит |
| Переполюсовка −30 В, плавкий предохранитель 0.05 Ом | 0.0 В / -0.0 В | 43.3 В | 0.00 А | -0.0 мДж | -0.00 мА | проходит |
| Выброс +50 В / 2 Ом / 50 мкс поверх 12 В | 19.1 В / 11.5 В | 6.0 В | 0.00 А | 0.0 мДж | -0.00 мА | проходит |
| Стресс: +100 В / 10 Ом / 1 мс поверх 12 В | 41.4 В / 11.2 В | 25.7 В | 3.01 А | 45.8 мДж | 0.02 мА | проходит |
| Постоянные 24 В на входе | 23.7 В / 0.0 В | 0.0 В | 0.00 А | 0.0 мДж | 0.00 мА | проходит |

### Вариант B — только 12 В (9–18 В): TVS SMBJ18A, MP1584 (рабочий вход до 28 В)

Предел по входу преобразователя: 28 В.

| Сценарий | Пик / минимум на входе преобр. | Обратное на Шоттки | Ток TVS макс. | Энергия TVS | Ток TVS в конце | Итог |
|---|---|---|---|---|---|---|
| Горячее подключение 12 В через кабель 1.5 мкГн | 11.5 В / -0.0 В | 0.0 В | 0.00 А | 0.0 мДж | 0.00 мА | проходит |
| Горячее подключение 12 В, плавкий предохранитель 0.05 Ом | 11.6 В / -0.0 В | -0.0 В | 0.00 А | 0.0 мДж | 0.00 мА | проходит |
| Горячее подключение 12 В, плавкий предохранитель, без электролита | 16.2 В / -0.0 В | 8.6 В | 0.00 А | 0.0 мДж | -0.00 мА | проходит |
| Переполюсовка −30 В | 0.0 В / -0.0 В | 43.1 В | 0.00 А | -0.0 мДж | -0.00 мА | проходит |
| Выброс +50 В / 2 Ом / 50 мкс поверх 12 В | 19.1 В / 11.5 В | 6.0 В | 0.00 А | 0.0 мДж | -0.00 мА | проходит |
| Стресс: +100 В / 10 Ом / 1 мс поверх 12 В | 23.5 В / 11.2 В | 8.7 В | 6.52 А | 73.0 мДж | 0.00 мА | проходит |
| Постоянные 24 В на входе | 21.8 В / -0.0 В | -0.0 В | 2.54 А | 104.0 мДж | 2543.57 мА | **НЕ проходит** |

## 4. Просадка VBAT у выводов модуля

Критерий: минимум не ниже 3.3 В (минимум питания Cat.1-модулей класса Air780E — уточнить по даташиту выбранного SKU); для запаса показан и 3.4 В. Выброс при сбросе нагрузки не выше 4.3 В. Дорожка до модуля 10 мОм / 5 нГн, керамика 22 мкФ у выводов.

Частота среза петли перебирается, потому что компенсацию конкретной микросхемы модель не знает: 0.5–1 кГц — случай, когда компенсацию из даташита не перенастроили под большую ёмкость (частота среза падает обратно пропорционально ёмкости выхода), 5–40 кГц — перенастроили.

### P1. GSM-подобный худший случай: пики 2 А по 577 мкс каждые 4.615 мс (расчёт §5.2)

Ограничение тока преобразователя 2 А. Минимум / максимум VBAT у модуля, В; столбцы — частота среза петли.

| Объёмная ёмкость (ESR) | 0.5 кГц | 1 кГц | 5 кГц | 15 кГц | 40 кГц |
|---|---|---|---|---|---|
| 100 мкФ (100 мОм) | 0.070 / 4.84 ✘ | 1.911 / 4.77 ✘ | 3.402 / 4.21 | 3.620 / 3.97 | 3.672 / 3.91 |
| 220 мкФ (60 мОм) | 1.916 / 4.32 ✘ | 2.843 / 4.28 ✘ | 3.590 / 4.01 | 3.695 / 3.89 | 3.715 / 3.86 |
| 470 мкФ (40 мОм) | 2.867 / 4.05 ✘ | 3.322 / 4.03 | 3.684 / 3.90 | 3.731 / 3.85 | 3.739 / 3.83 |
| 1000 мкФ (25 мОм) | 3.343 / 3.92 | 3.561 / 3.91 | 3.731 / 3.85 | 3.752 / 3.83 | 3.754 / 3.82 |
| 2200 мкФ (18 мОм) | 3.580 / 3.85 | 3.680 / 3.85 | 3.754 / 3.83 | 3.761 / 3.82 | 3.762 / 3.82 |

Ограничение тока преобразователя 3 А. Минимум / максимум VBAT у модуля, В; столбцы — частота среза петли.

| Объёмная ёмкость (ESR) | 0.5 кГц | 1 кГц | 5 кГц | 15 кГц | 40 кГц |
|---|---|---|---|---|---|
| 100 мкФ (100 мОм) | 0.070 / 4.84 ✘ | 1.911 / 4.73 ✘ | 3.402 / 4.17 | 3.620 / 3.96 | 3.672 / 3.91 |
| 220 мкФ (60 мОм) | 1.916 / 4.32 ✘ | 2.843 / 4.26 ✘ | 3.590 / 3.99 | 3.695 / 3.88 | 3.715 / 3.86 |
| 470 мкФ (40 мОм) | 2.867 / 4.05 ✘ | 3.322 / 4.02 | 3.684 / 3.89 | 3.731 / 3.85 | 3.739 / 3.84 |
| 1000 мкФ (25 мОм) | 3.343 / 3.92 | 3.561 / 3.91 | 3.731 / 3.85 | 3.752 / 3.83 | 3.754 / 3.82 |
| 2200 мкФ (18 мОм) | 3.580 / 3.85 | 3.680 / 3.85 | 3.754 / 3.83 | 3.761 / 3.82 | 3.762 / 3.82 |

### P2. LTE Cat.1-подобный: подкадры 1 мс, 0.5–1.1 А, случайная занятость 60 %

Ограничение тока преобразователя 2 А. Минимум / максимум VBAT у модуля, В; столбцы — частота среза петли.

| Объёмная ёмкость (ESR) | 0.5 кГц | 1 кГц | 5 кГц | 15 кГц | 40 кГц |
|---|---|---|---|---|---|
| 100 мкФ (100 мОм) | 1.994 / 5.47 ✘ | 2.896 / 4.71 ✘ | 3.597 / 4.00 | 3.709 / 3.88 | 3.736 / 3.85 |
| 220 мкФ (60 мОм) | 2.887 / 4.64 ✘ | 3.342 / 4.26 | 3.693 / 3.90 | 3.746 / 3.84 | 3.759 / 3.83 |
| 470 мкФ (40 мОм) | 3.348 / 4.21 | 3.571 / 4.02 | 3.740 / 3.85 | 3.765 / 3.82 | 3.770 / 3.82 |
| 1000 мкФ (25 мОм) | 3.578 / 4.00 | 3.685 / 3.91 | 3.765 / 3.82 | 3.775 / 3.81 | 3.778 / 3.81 |
| 2200 мкФ (18 мОм) | 3.693 / 3.89 | 3.742 / 3.85 | 3.776 / 3.81 | 3.780 / 3.81 | 3.781 / 3.81 |

Ограничение тока преобразователя 3 А. Минимум / максимум VBAT у модуля, В; столбцы — частота среза петли.

| Объёмная ёмкость (ESR) | 0.5 кГц | 1 кГц | 5 кГц | 15 кГц | 40 кГц |
|---|---|---|---|---|---|
| 100 мкФ (100 мОм) | 1.994 / 5.47 ✘ | 2.896 / 4.71 ✘ | 3.597 / 4.00 | 3.709 / 3.88 | 3.736 / 3.85 |
| 220 мкФ (60 мОм) | 2.887 / 4.64 ✘ | 3.342 / 4.26 | 3.693 / 3.90 | 3.746 / 3.84 | 3.759 / 3.83 |
| 470 мкФ (40 мОм) | 3.348 / 4.21 | 3.571 / 4.02 | 3.740 / 3.85 | 3.765 / 3.82 | 3.770 / 3.82 |
| 1000 мкФ (25 мОм) | 3.578 / 4.00 | 3.685 / 3.91 | 3.765 / 3.82 | 3.775 / 3.81 | 3.778 / 3.81 |
| 2200 мкФ (18 мОм) | 3.693 / 3.89 | 3.742 / 3.85 | 3.776 / 3.81 | 3.780 / 3.81 | 3.781 / 3.81 |

### P3. Длинный пик 2 А на 20 мс (регистрация/передача на максимальной мощности)

Ограничение тока преобразователя 2 А. Минимум / максимум VBAT у модуля, В; столбцы — частота среза петли.

| Объёмная ёмкость (ESR) | 0.5 кГц | 1 кГц | 5 кГц | 15 кГц | 40 кГц |
|---|---|---|---|---|---|
| 100 мкФ (100 мОм) | 0.024 / 7.90 ✘ | 1.911 / 5.85 ✘ | 3.403 / 4.21 | 3.622 / 3.97 | 3.676 / 3.91 |
| 220 мкФ (60 мОм) | 1.892 / 5.86 ✘ | 2.843 / 4.83 ✘ | 3.590 / 4.01 | 3.695 / 3.89 | 3.721 / 3.86 |
| 470 мкФ (40 мОм) | 2.856 / 4.81 ✘ | 3.322 / 4.30 | 3.684 / 3.90 | 3.731 / 3.85 | 3.743 / 3.84 |
| 1000 мкФ (25 мОм) | 3.337 / 4.28 | 3.561 / 4.04 | 3.731 / 3.85 | 3.752 / 3.83 | 3.758 / 3.82 |
| 2200 мкФ (18 мОм) | 3.578 / 4.02 | 3.680 / 3.91 | 3.754 / 3.83 | 3.762 / 3.82 | 3.765 / 3.81 |

Ограничение тока преобразователя 3 А. Минимум / максимум VBAT у модуля, В; столбцы — частота среза петли.

| Объёмная ёмкость (ESR) | 0.5 кГц | 1 кГц | 5 кГц | 15 кГц | 40 кГц |
|---|---|---|---|---|---|
| 100 мкФ (100 мОм) | 0.024 / 7.56 ✘ | 1.911 / 5.67 ✘ | 3.403 / 4.18 | 3.622 / 3.96 | 3.676 / 3.90 |
| 220 мкФ (60 мОм) | 1.892 / 5.69 ✘ | 2.843 / 4.74 ✘ | 3.590 / 3.99 | 3.695 / 3.88 | 3.721 / 3.86 |
| 470 мкФ (40 мОм) | 2.856 / 4.72 ✘ | 3.322 / 4.26 | 3.684 / 3.90 | 3.731 / 3.85 | 3.743 / 3.84 |
| 1000 мкФ (25 мОм) | 3.337 / 4.24 | 3.561 / 4.02 | 3.731 / 3.85 | 3.752 / 3.83 | 3.758 / 3.82 |
| 2200 мкФ (18 мОм) | 3.578 / 4.00 | 3.680 / 3.90 | 3.754 / 3.83 | 3.762 / 3.82 | 3.765 / 3.81 |

✘ — не выполнен хотя бы один критерий.

## 5. Удержание питания при пропадании линии 12 В

Время отсчитывается от пропадания 12 В. Объёмная ёмкость 1000 мкФ.

| Вход | Нагрузка | Вход < 9 В | VBAT < 3.3 В (модем) | VBAT < 3.0 В | Питание MCU/FRAM < 2.7 В |
|---|---|---|---|---|---|
| 10 мкФ керамика + 47 мкФ электролит | модем в ожидании, 100 мА | 3.43 мс | 12.74 мс | 15.90 мс | 16.95 мс |
| 10 мкФ керамика + 47 мкФ электролит | идёт передача, 500 мА в среднем | 0.61 мс | 2.45 мс | 3.09 мс | 3.30 мс |
| 10 мкФ керамика + 47 мкФ электролит | передача; модем отключается ключом, когда вход < 9 В | 0.63 мс | — | — | — |
| +100 мкФ | модем в ожидании, 100 мА | 9.43 мс | 26.33 мс | 29.77 мс | 30.92 мс |
| +100 мкФ | идёт передача, 500 мА в среднем | 1.69 мс | 5.04 мс | 5.73 мс | 5.96 мс |

## Графики

- `sim/out/input_stage.png`
- `sim/out/vbat_P1_1000Hz.png`
- `sim/out/vbat_P1_15000Hz.png`
- `sim/out/vbat_P2_1000Hz.png`
- `sim/out/vbat_P2_15000Hz.png`
- `sim/out/vbat_P3_1000Hz.png`
- `sim/out/vbat_P3_15000Hz.png`
- `sim/out/holdup.png`
- `sim/out/power_A_hot30.png`
- `sim/out/power_A_hot30_noel.png`
- `sim/out/power_A_surge50.png`

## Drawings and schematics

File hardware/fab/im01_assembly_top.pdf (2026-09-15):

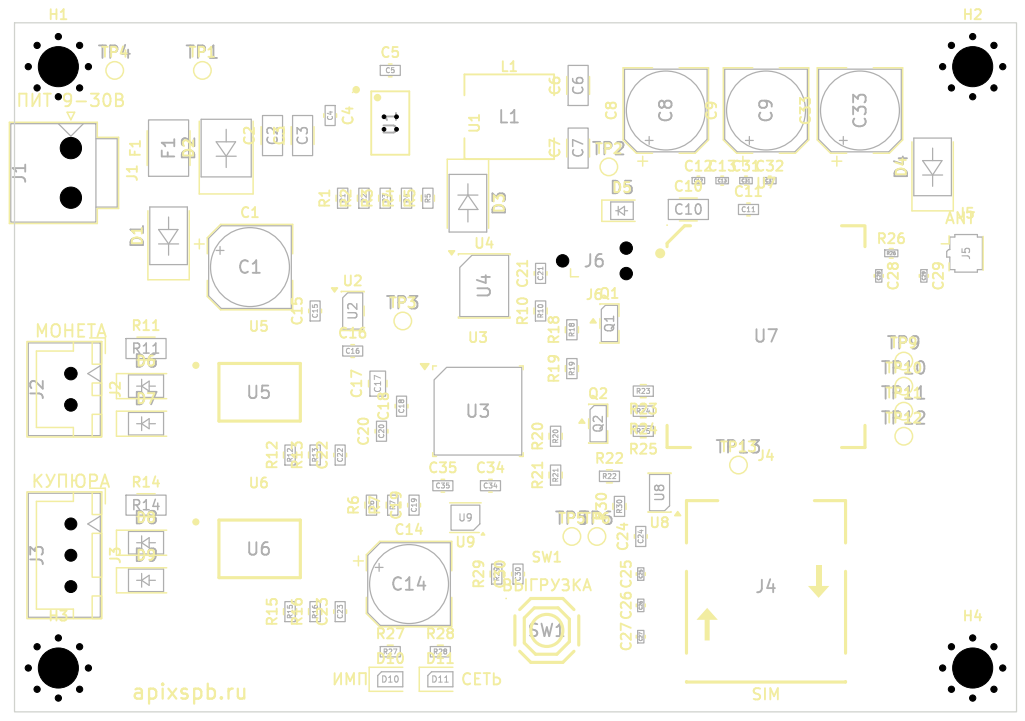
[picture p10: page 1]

ANT þÿ"þÿ9-30 þÿ" þÿ#.  apixspb.ru

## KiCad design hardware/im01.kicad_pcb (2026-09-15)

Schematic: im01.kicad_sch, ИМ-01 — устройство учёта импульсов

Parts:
C1: 47uF/50V; CP_Elec_6.3x7.7; MPN RVT1H470M0607; LCSC C970679
C2, C3: 4.7uF; C_1206_3216Metric; MPN 1206B475K500NT; LCSC C29823
C4, C5, C11, C18, C19, C20, C21, C22, C23, C24, C30, C34, C35: 100nF; C_0603_1608Metric; MPN CC0603KRX7R9BB104; LCSC C14663
C6, C7, C10: 22uF; C_1206_3216Metric; MPN CL31B226KPHNNNE; LCSC C87996
C8, C9, C14, C33: 470uF/6.3V; CP_Elec_6.3x7.7; MPN MA6.3V470M6X8; LCSC C54321567
C12, C25, C26, C27: 33pF; C_0402_1005Metric; MPN 0402CG330J500NT; LCSC C1562
C13: 10pF; C_0402_1005Metric; MPN CL05C100JB5NNNC; LCSC C32949
C15, C16: 1uF; C_0603_1608Metric; MPN CL10A105KB8NNNC; LCSC C15849
C17: 10uF; C_0805_2012Metric; MPN CL21A106KAYNNNE; LCSC C15850
C28, C29: 10pF; C_0402_1005Metric; MPN CL05C100JB5NNNC; LCSC C32949; not fitted
C31: 3.9pF; C_0402_1005Metric; MPN 0402CG3R9C500NT; LCSC C1566
C32: 1.8pF; C_0402_1005Metric; MPN 0402CG1R8C500NT; LCSC C1553
D1, D3: SS36; D_SMA; MPN SS36; LCSC C16015
D2: SMBJ33A; D_SMB; MPN SMBJ33A; LCSC C353366
D4: SMAZ5V1; D_SMA; MPN SMAZ5V1-13-F; LCSC C154748
D5: BAT54WS; D_SOD-323; MPN BAT54WS; LCSC C3040452
D6, D7, D8, D9: 1N4148W; D_SOD-123; MPN 1N4148W; LCSC C81598
D10: зелёный; LED_0805_2012Metric; MPN NCD0805G1; LCSC C84260
D11: красный; LED_0805_2012Metric; MPN NCD0805R1; LCSC C84256
F1: 0.5A/60V; Fuse_1812_4532Metric; MPN mSMD050-60V; LCSC C70113
H1, H2, H3, H4: M3; MountingHole_3.2mm_M3_Pad_Via
J1: ПИТАНИЕ 9-30В; JST_VH_B2P-VH_1x02_P3.96mm_Vertical; MPN B2P-VH(LF)(SN); LCSC C160315
J2: COIN; JST_XH_B2B-XH-A_1x02_P2.50mm_Vertical; MPN B2B-XH-A(LF)(SN); LCSC C158012
J3: BILL; JST_XH_B3B-XH-A_1x03_P2.50mm_Vertical; MPN B3B-XH-A(LF)(SN); LCSC C144394
J4: NANO SIM; SIM-SMD_NANO-SIM-XG6P-H1.35; MPN NANO SIM XG6P H1.35; LCSC C7529386
J5: U.FL; U.FL_Hirose_U.FL-R-SMT-1_Vertical; MPN U.FL-R-SMT-1(80); LCSC C88374
J6: SWD; Tag-Connect_TC2030-IDC-NL_2x03_P1.27mm_Vertical
L1: 10uH; IND-SMD_L7.3-W6.6_MHCI06030; MPN SLO0630H100MTT; LCSC C207842
Q1, Q2: 2N7002; SOT-23; MPN 2N7002; LCSC C8545
R1: 270k; R_0603_1608Metric; MPN 0603WAF2703T5E; LCSC C22965
R2: 49.9k; R_0603_1608Metric; MPN 0603WAF4992T5E; LCSC C23184
R3, R4: 41.2k; R_0603_1608Metric; MPN 0603WAF4122T5E; LCSC C23166
R5, R7, R10, R13, R16, R22, R29: 10k; R_0603_1608Metric; MPN 0603WAF1002T5E; LCSC C25804
R6, R19, R21: 100k; R_0603_1608Metric; MPN 0603WAF1003T5E; LCSC C25803
R11, R14: 2.2k; R_1206_3216Metric; MPN 1206W4F2201T5E; LCSC C17948
R12, R15: 4.7k; R_0603_1608Metric; MPN 0603WAF4701T5E; LCSC C23162
R18, R20, R27, R28: 1k; R_0603_1608Metric; MPN 0603WAF1001T5E; LCSC C21190
R23, R24, R25: 22Ω; R_0603_1608Metric; MPN 0603WAF220JT5E; LCSC C23345
R26: 0Ω; R_0402_1005Metric; MPN 0402WGF0000TCE; LCSC C17168
R30: 15k; R_0603_1608Metric; MPN 0603WAF1502T5E; LCSC C22809
SW1: ВЫГРУЗКА; SW-SMD_4P-L5.1-W5.1-P3.70-LS6.5-TL_H1.5; MPN TS-1187A-B-A-B; LCSC C318884
TP1: VIN; TestPoint_Pad_D1.0mm
TP2: VBAT; TestPoint_Pad_D1.0mm
TP3: +3V3; TestPoint_Pad_D1.0mm
TP4: GND; TestPoint_Pad_D1.0mm
TP5: MCU_DBG_TX; TestPoint_Pad_D1.0mm
TP6: MCU_DBG_RX; TestPoint_Pad_D1.0mm
TP9: USB_DP; TestPoint_Pad_D1.0mm
TP10: USB_DN; TestPoint_Pad_D1.0mm
TP11: VBUS; TestPoint_Pad_D1.0mm
TP12: USB_BOOT; TestPoint_Pad_D1.0mm
TP13: NET_STATUS; TestPoint_Pad_D1.0mm
U1: LMR16020; SOIC-8_L4.9-W3.9-P1.27-LS6.0-BL-EP; MPN LMR16020PDDAR; LCSC C190006
U2: ME6211C33; SOT-23-5; MPN ME6211C33M5G-N; LCSC C82942
U3: STM32G030K8T6; LQFP-32_7x7mm_P0.8mm; MPN STM32G030K8T6TR; LCSC C724044
U4: FM25L16B; SOIC-8_3.9x4.9mm_P1.27mm; MPN FM25L16B-GTR; LCSC C466849
U5, U6: EL817S1(B); SOP-4_L6.5-W4.6-P2.54-LS10.2-TL; MPN EL817S1(B)(TU)-F; LCSC C63268
U7: EG800K-EU; LGA-109_L17.7-W15.8-AIR780E; MPN EG800KEULC-I03-SNNSA; LCSC C44008839
U8: SRV05-4; SOT-23-6; MPN SRV05-4; LCSC C2836319
U9: TXS0102; VSSOP-8_2.3x2mm_P0.5mm; MPN TXS0102DCUR; LCSC C53434

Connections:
+3V3: C16.1, C17.1, C18.1, C21.1, C35.1, J6.1 (VCC), R10.1, R12.1, R15.1, R29.1, TP3.1, U2.5 (V_{OUT}), U3.4 (VDD), U4.3 (~WP), U4.7 (~HOLD), U4.8 (VDD), U9.7 (VCCB)
ANT_MOD: C28.1, R26.1, U7.35 (ANT_MAIN)
ANT_OUT: C29.1, J5.1 (In), R26.2
BILL_IN: C23.1, R16.2, U3.14 (PA7), U3.20 (PC6)
BILL_LA: D8.1 (K), D9.1 (K), U6.1 (AN)
BILL_OC: R15.2, R16.1, U6.4 (COL)
BILL_PULSE: D9.2 (A), J3.2, U6.2 (CAT)
BILL_R: D8.2 (A), R14.2
BILL_V12: J3.1, R14.1
BOOT: C5.1, U1.1 (BOOT)
BTN: C30.1, R29.2, SW1.1 (A), U3.32 (PB8)
COIN_IN: C22.1, R13.2, U3.13 (PA6), U3.18 (PA8)
COIN_LA: D6.1 (K), D7.1 (K), U5.1 (AN)
COIN_OC: R12.2, R13.1, U5.4 (COL)
COIN_PULSE: D7.2 (A), J2.2, U5.2 (CAT)
COIN_R: D6.2 (A), R11.2
COIN_V12: J2.1, R11.1
EN: R1.2, R2.1, U1.3 (EN)
FB: R4.2, R5.1, U1.5 (FB)
FRAM_CS: R10.2, U3.26 (PA15), U4.1 (~CS)
GND: C1.2, C2.2, C3.2, C4.2, C6.2, C7.2, C8.2, C9.2, C10.2, C11.2, C12.2, C13.2, C14.2, C15.2, C16.2, C17.2, C18.2, C19.2, C20.2, C21.2, C22.2, C23.2, C24.2, C25.2, C26.2, C27.2, C28.2, C29.2, C30.2, C31.2, C32.2, C33.2, C34.2, C35.2, D2.2 (A), D3.2 (A), D4.2 (A), D10.1 (K), D11.1 (K), H1.1, H2.1, H3.1, H4.1, J1.2, J4.5 (GND), J4.8 (GND), J4.9 (GND), J4.10 (GND), J4.11 (GND), J5.2 (Ext), J6.5 (GND), Q1.2 (S), Q2.2 (S), R2.2, R3.2, R5.2, R7.2, R19.2, R21.2, SW1.4 (D), TP4.1, U1.7 (GND), U1.9 (EP), U2.2 (V_{SS}), U3.5 (VSS), U4.4 (VSS), U5.3 (EM), U6.3 (EM), U7.1 (GND), U7.10 (GND), U7.27 (GND), U7.34 (GND), U7.36 (GND), U7.37 (GND), U7.40 (GND), U7.41 (GND), U7.45 (GND), U7.46 (GND), U7.47 (GND), U7.48 (GND), U7.70 (GND), U7.71 (GND), U7.72 (GND), U7.73 (GND), U7.88 (GND), U7.89 (GND), U7.90 (GND), U7.91 (GND), U7.92 (GND), U7.93 (GND), U7.94 (GND), U7.95 (GND), U8.2 (VN), U9.2 (GND)
LED1_A: D10.2 (A), R27.2
LED2_A: D11.2 (A), R28.2
LED_PULSE: R27.1, U3.30 (PB6)
LED_STATUS: R28.1, U3.31 (PB7)
MCU_DBG_RX: TP6.1, U3.23 (PA10/PA12)
MCU_DBG_TX: TP5.1, U3.22 (PA9/PA11)
MCU_RX: U3.10 (PA3), U9.1 (B2)
MCU_TX: U3.9 (PA2), U9.8 (B1)
MODEM_PWRKEY: Q1.3 (D), U7.7 (PWRKEY)
MODEM_RESET_N: Q2.3 (D), U7.15 (RESET_N)
MODEM_RXD: U7.17 (MAIN_RXD), U9.5 (A1)
MODEM_TXD: U7.18 (MAIN_TXD), U9.4 (A2)
NET_STATUS: TP13.1, U7.16 (NET_STATUS)
NRST: C20.1, J6.3 (~RESET), U3.6 (NRST)
PWRKEY_CTL: R18.1, U3.15 (PB0)
PWRKEY_G: Q1.1 (G), R18.2, R19.1
RESET_CTL: R20.1, U3.16 (PB1)
RESET_G: Q2.1 (G), R20.2, R21.1
RT: R3.1, U1.4 (RT/SYNC)
SIM_CLK: C27.1, J4.3 (CLK), R25.2, U8.4 (IO3)
SIM_CLK_M: R25.1, U7.13 (USIM1_CLK)
SIM_DATA: C25.1, J4.7 (I/O), R23.2, R30.2, U8.1 (IO1)
SIM_DATA_M: R23.1, U7.11 (USIM1_DATA)
SIM_RST: C26.1, J4.2 (RST), R24.2, U8.3 (IO2)
SIM_RST_M: R24.1, U7.12 (USIM1_RST)
SIM_VDD: C24.1, J4.1 (VCC), R30.1, U7.14 (USIM1_VDD), U8.5 (VP)
SPI_MISO: U3.28 (PB4), U4.2 (SO)
SPI_MOSI: U3.29 (PB5), U4.5 (SI)
SPI_SCK: U3.27 (PB3), U4.6 (SCK)
SW: C5.2, D3.1 (K), L1.1, U1.8 (SW)
SWCLK: J6.4 (SWCLK), U3.25 (PA14)
SWDIO: J6.2 (SWDIO), U3.24 (PA13)
USB_BOOT: TP12.1, U7.82 (USB_BOOT/KP_MKOUT[4])
USB_DN: TP10.1, U7.60 (USB_DM)
USB_DP: TP9.1, U7.59 (USB_DP)
VBAT: C6.1, C7.1, C8.1, C9.1, C10.1, C11.1, C12.1, C13.1, C31.1, C32.1, C33.1, D4.1 (K), D5.2 (A), L1.2, R4.1, TP2.1, U7.42 (VBAT), U7.43 (VBAT)
VBUS: TP11.1, U7.61 (USB_VBUS)
VDDEXT_SENSE: R22.2, U3.17 (PB2)
VDD_EXT: C34.1, R22.1, U7.24 (VDD_EXT), U9.3 (VCCA), U9.6 (OE)
VIN: C1.1, C2.1, C3.1, C4.1, D1.1 (K), D2.1 (K), R1.1, TP1.1, U1.2 (VIN)
VIN_CONN: F1.1, J1.1
VIN_F: D1.2 (A), F1.2, R6.1
VMCU_IN: C14.1, C15.1, D5.1 (K), U2.1 (V_{IN}), U2.3 (CE)
VSENSE: C19.1, R6.2, R7.1, U3.7 (PA0)

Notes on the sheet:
Вход питания 9–30 В
Преобразователь VBAT 3.84 В
Питание MCU и FRAM
MCU STM32G030K8
FRAM
Вход COIN
Вход BILL
Модем LTE Cat.1 bis
SIM-карта
Антенна
Индикация и кнопка
Отладка и крепёж
Флажки питания (ERC)

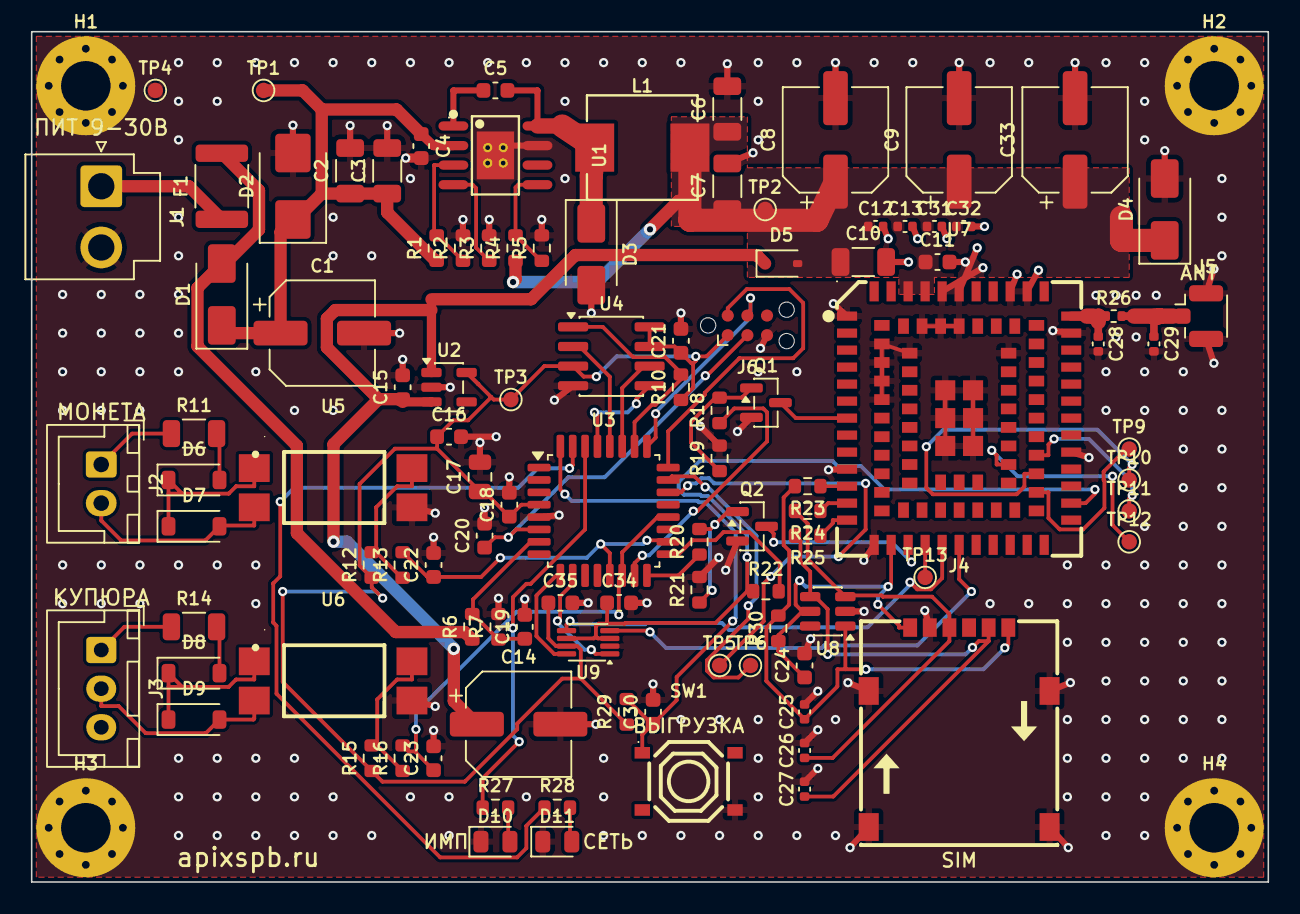
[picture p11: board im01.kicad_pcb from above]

Board: 2 copper layers, 80.0 x 55.0 mm, 108 parts (0 on the bottom side), 65 nets.

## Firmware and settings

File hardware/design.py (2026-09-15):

"""ИМ-01: единственное описание схемы.

Детали, номиналы, посадочные места, артикулы LCSC и соединения. Из этого файла генерируются схема
(gen_sch.py), плата (gen_pcb.py) и перечень компонентов (gen_bom.py), поэтому схема, плата и BOM
не могут разойтись между собой.

Номиналы обоснованы в docs/step1-analog-sim.md и docs/hardware.md.
"""
from __future__ import annotations

from dataclasses import dataclass, field

LCSC_LIB = "im01_lcsc"  # символы и посадочные места, загруженные с LCSC: hardware/lib/lcsc.*


@dataclass
class Part:
    ref: str
    value: str
    symbol: str
    footprint: str
    pins: dict[str, str | None]
    lcsc: str = ""
    mpn: str = ""
    block: str = ""
    dnp: bool = False
    in_bom: bool = True
    note: str = ""


FP = {
    ("R", "0402"): "Resistor_SMD:R_0402_1005Metric",
    ("R", "0603"): "Resistor_SMD:R_0603_1608Metric",
    ("R", "1206"): "Resistor_SMD:R_1206_3216Metric",
    ("C", "0402"): "Capacitor_SMD:C_0402_1005Metric",
    ("C", "0603"): "Capacitor_SMD:C_0603_1608Metric",
    ("C", "0805"): "Capacitor_SMD:C_0805_2012Metric",
    ("C", "1206"): "Capacitor_SMD:C_1206_3216Metric",
}

# Резисторы и конденсаторы: номинал -> (корпус, артикул LCSC, партномер)
RES = {
    "0R_0402": ("0402", "C17168", "0402WGF0000TCE"),
    "0R": ("0603", "C21189", "0603WAF0000T5E"),
    "22R": ("0603", "C23345", "0603WAF220JT5E"),
    "1k": ("0603", "C21190", "0603WAF1001T5E"),
    "4.7k": ("0603", "C23162", "0603WAF4701T5E"),
    "10k": ("0603", "C25804", "0603WAF1002T5E"),
    "15k": ("0603", "C22809", "0603WAF1502T5E"),
    "41.2k": ("0603", "C23166", "0603WAF4122T5E"),
    "49.9k": ("0603", "C23184", "0603WAF4992T5E"),
    "100k": ("0603", "C25803", "0603WAF1003T5E"),
    "270k": ("0603", "C22965", "0603WAF2703T5E"),
    "2.2k_1206": ("1206", "C17948", "1206W4F2201T5E"),
}
CAP = {
    "10pF": ("0402", "C32949", "CL05C100JB5NNNC"),
    "33pF": ("0402", "C1562", "0402CG330J500NT"),
    "100nF": ("0603", "C14663", "CC0603KRX7R9BB104"),
    "1uF": ("0603", "C15849", "CL10A105KB8NNNC"),
    "10uF": ("0805", "C15850", "CL21A106KAYNNNE"),
    "22uF": ("1206", "C87996", "CL31B226KPHNNNE"),
    "4.7uF_50V": ("1206", "C29823", "1206B475K500NT"),
}

PARTS: list[Part] = []


def add(part: Part) -> Part:
    PARTS.append(part)
    return part


def R(ref, key, a, b, block, **kw):
    size, lcsc, mpn = RES[key]
    value = key.split("_")[0].replace("R", "Ω") if key.startswith(("0R", "22R")) else key.split("_")[0]
    return add(Part(ref, value, "Device:R", FP[("R", size)], {"1": a, "2": b}, lcsc, mpn, block, **kw))


def C(ref, key, a, b, block, **kw):
    size, lcsc, mpn = CAP[key]
    return add(Part(ref, key.split("_")[0], "Device:C", FP[("C", size)], {"1": a, "2": b}, lcsc, mpn, block, **kw))


def CP(ref, value, plus, minus, block, lcsc, mpn, fp="Capacitor_SMD:CP_Elec_6.3x7.7", **kw):
    return add(Part(ref, value, "Device:C_Polarized", fp, {"1": plus, "2": minus}, lcsc, mpn, block, **kw))


def D(ref, value, anode, cathode, block, lcsc, mpn, fp, symbol="Device:D", **kw):
    return add(Part(ref, value, symbol, fp, {"1": cathode, "2": anode}, lcsc, mpn, block, **kw))


def TP(ref, net, block, note=""):
    return add(Part(ref, net, "Connector:TestPoint", "TestPoint:TestPoint_Pad_D1.0mm", {"1": net},
                    block=block, in_bom=False, note=note))


# ================================================================ вход питания
B = "Вход питания 9–30 В"
add(Part("J1", "ПИТАНИЕ 9-30В", "Connector_Generic:Conn_01x02",
         "Connector_JST:JST_VH_B2P-VH_1x02_P3.96mm_Vertical", {"1": "VIN_CONN", "2": "GND"},
         "C160315", "B2P-VH(LF)(SN)", B, note="1 = +, 2 = GND"))
add(Part("F1", "0.5A/60V", "Device:Polyfuse", "Fuse:Fuse_1812_4532Metric", {"1": "VIN_CONN", "2": "VIN_F"},
         "C70113", "mSMD050-60V", B))
D("D1", "SS36", "VIN_F", "VIN", B, "C16015", "SS36", "Diode_SMD:D_SMA", symbol="Device:D_Schottky",
  note="защита от переполюсовки, 60 В: при −30 В звон кабеля даёт 43 В")
D("D2", "SMBJ33A", "GND", "VIN", B, "C353366", "SMBJ33A", "Diode_SMD:D_SMB", symbol="Device:D_Zener",
  note="TVS однонаправленный")
CP("C1", "47uF/50V", "VIN", "GND", B, "C970679", "RVT1H470M0607", note="гасит звон при горячем подключении")
C("C2", "4.7uF_50V", "VIN", "GND", B)
C("C3", "4.7uF_50V", "VIN", "GND", B)
R("R6", "100k", "VIN_F", "VSENSE", B, note="датчик пропадания 12 В → АЦП MCU")
R("R7", "10k", "VSENSE", "GND", B)
C("C19", "100nF", "VSENSE", "GND", B)

# ================================================================ преобразователь 3.84 В
B = "Преобразователь VBAT 3.84 В"
add(Part("U1", "LMR16020", f"{LCSC_LIB}:LMR16020PDDAR", f"{LCSC_LIB}:SOIC-8_L4.9-W3.9-P1.27-LS6.0-BL-EP",
         {"1": "BOOT", "2": "VIN", "3": "EN", "4": "RT", "5": "FB", "6": None, "7": "GND", "8": "SW", "9": "GND"},
         "C190006", "LMR16020PDDAR", B, note="60 В, 2 А; 600 кГц"))
C("C4", "100nF", "VIN", "GND", B, note="у вывода VIN")
R("R1", "270k", "VIN", "EN", B, note="включение 7.5 В, выключение 6.5 В")
R("R2", "49.9k", "EN", "GND", B)
R("R3", "41.2k", "RT", "GND", B, note="600 кГц")
C("C5", "100nF", "BOOT", "SW", B)
add(Part("L1", "10uH", "Device:L", f"{LCSC_LIB}:IND-SMD_L7.3-W6.6_MHCI06030", {"1": "SW", "2": "VBAT"},
         "C207842", "SLO0630H100MTT", B, note="10 мкГн, насыщение 5.5 А"))
D("D3", "SS36", "GND", "SW", B, "C16015", "SS36", "Diode_SMD:D_SMA", symbol="Device:D_Schottky")
R("R4", "41.2k", "VBAT", "FB", B, note="VBAT = 0.75 × (1 + 41.2/10) = 3.84 В")
R("R5", "10k", "FB", "GND", B)
C("C6", "22uF", "VBAT", "GND", B)
C("C7", "22uF", "VBAT", "GND", B)
CP("C8", "470uF/6.3V", "VBAT", "GND", B, "C54321567", "MA6.3V470M6X8", note="полимер 20 мОм; C8+C9 = 940 мкФ")
CP("C9", "470uF/6.3V", "VBAT", "GND", B, "C54321567", "MA6.3V470M6X8")
D("D4", "SMAZ5V1", "GND", "VBAT", B, "C154748", "SMAZ5V1-13-F", "Diode_SMD:D_SMA", symbol="Device:D_Zener",
  note="по руководству Air780E: стабилитрон 5.1 В 1 Вт у VBAT")

# ================================================================ питание MCU
B = "Питание MCU и FRAM"
D("D5", "BAT54WS", "VBAT", "VMCU_IN", B, "C3040452", "BAT54WS", "Diode_SMD:D_SOD-323",
  symbol="Device:D_Schottky", note="отделяет MCU от просадок модема и пропадания питания")
CP("C14", "470uF/6.3V", "VMCU_IN", "GND", B, "C54321567", "MA6.3V470M6X8", note="запас MCU > 30 мс")
C("C15", "1uF", "VMCU_IN", "GND", B)
add(Part("U2", "ME6211C33", "Regulator_Linear:ME6211C33M5", "Package_TO_SOT_SMD:SOT-23-5",
         {"1": "VMCU_IN", "2": "GND", "3": "VMCU_IN", "4": None, "5": "+3V3"}, "C82942", "ME6211C33M5G-N", B))
C("C16", "1uF", "+3V3", "GND", B)
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

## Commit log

2026-09-15 chore: каркас репозитория ИМ-01 и исходное задание
2026-09-15 feat(sim): шаг 1 — аналоговая симуляция входного каскада, защиты входа, VBAT и удержания
    Критерии §9 шага 1 выполнены с поправками: подтяжка оптопары 4.7 кОм,
    последовательный диод в цепи светодиода, преобразователь класса 60 В
    вместо MP1584 (вход 9–30 В ему не по паспорту), Шоттки на 60 В, датчик
    пропадания 12 В и ключ питания модема. Порог длительности 15 мс вместо
    10 мс предложен, но требует согласия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
2026-09-15 feat(hardware): схема и расстановка платы ИМ-01 на Quectel EG800K-EU
    design.py — единственное описание схемы (110 деталей, артикулы LCSC),
    генераторы схемы и платы, проверка по библиотекам. Модем заменён на
    EG800K-EU: у Air780E нет B20/B7, у Air780EU нет документации. Под логику
    1.8 В добавлен TXS0102, под VBAT от 3.4 В — третий полимер 470 мкФ.
    Трассировка и файлы для производства — следующим шагом.
    [im01.kicad_pcb, im01.kicad_sch]
2026-09-15 feat(hardware): перечень комплектующих с ценами LCSC и РФ (ЧипДип, efind)
    gen_bom.py собирает Excel из design.py: артикулы, наличие и цена на
    LCSC (курс ЦБ), лучшая цена в РФ на нужное количество (только если на
    складе хватает на партию), с проверкой на правдоподобие — цена в РФ
    ниже половины оптовой цены LCSC отбрасывается как сбой разбора страницы.
    Свод на 500 плат: 842 ₽/плата комплектующих (без платы, корпуса, ант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
    [ИМ-01_перечень_комплектующих.xlsx]
2026-09-15 feat(hardware): разводка платы ИМ-01, файлы для JLCPCB, виртуальная модель
    Три критичные цепи (антенна, узел SW, путь VBAT) разведены по заданной
    геометрии и зафиксированы, остальное — Freerouting; земля досоединяется
    по отчёту DRC. Итог: ERC 0 ошибок, DRC 0 нарушений и 0 неподключённых,
    сверка платы со схемой — 0 расхождений. fab/: гербер-архив, BOM и CPL
    для JLCPCB, PDF схемы и сборочного чертежа, STEP и 3D-вид.
    sim/run_final.py — м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
    [im01-B_Cu.gbl, im01-B_Mask.gbs, im01-B_Paste.gbp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]
2026-09-15 chore: не хранить файлы-блокировки LibreOffice
2026-09-15 chore: скрипт сборки архива с полной документацией
2026-09-15 docs: добавить архив полной документации rev.A
    Архив со всеми материалами по шагу 5 (плата): описание, картинки платы и
    симуляции, перечень комплектующих, схема/сборочный чертёж, файлы для
    заказа на JLCPCB. Кладу в репозиторий (а не только в release/, который
    не версионируется), чтобы была постоянная ссылка для скачивания.
